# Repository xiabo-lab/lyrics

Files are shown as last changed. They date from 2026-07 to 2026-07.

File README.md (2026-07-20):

# carlyrics on Raspberry Pi 5 — Raspberry Pi OS **Lite** (64-bit)

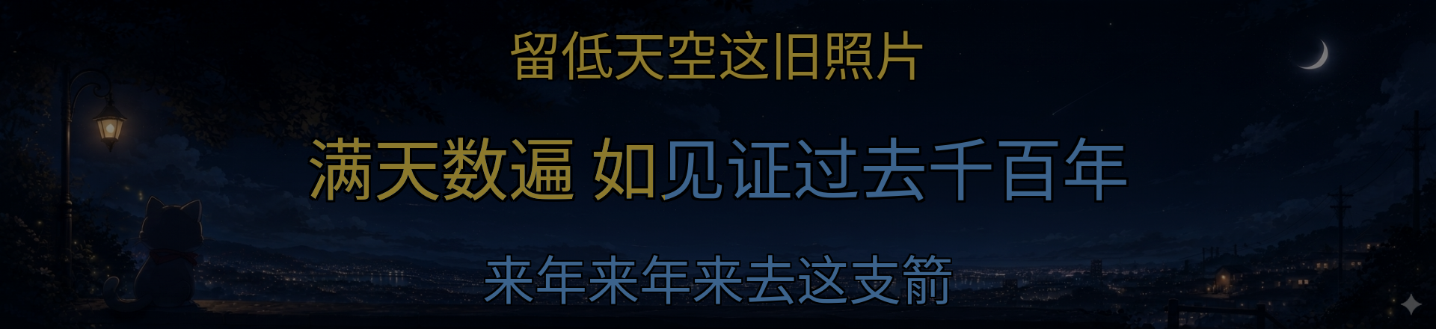
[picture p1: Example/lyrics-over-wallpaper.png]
carlyrics: time-synced, karaoke-style lyrics scrolling over a background picture on the in-car bar display


> Your phone plays music over Bluetooth; the Pi reads the playback position and
> scrolls **time-synced, karaoke-style lyrics** on a bar display in the car — no
> app on the phone, nothing to tap while driving.

Step-by-step setup for the car lyric display on a **Raspberry Pi 5** running the
**64-bit _Lite_ (console-only, no desktop)** image. Tested end-to-end on a **Pi 5
1GB**; any Pi 5 (1/2/4/8 GB) works — the app is light and never decodes audio.
**No source-code changes are required**; the code is identical to the Pi Zero 2W
build.

> 📱 **Just want to use the display once it's running?** See the
> **[First-Time Setup Guide](SETUP.md)** — a touchscreen walkthrough of every
> on-screen menu (fonts, background, Bluetooth, Wi-Fi, clock format) plus
> day-to-day use. This README covers the one-time Pi install below.

> ⚠️ **Use the _Lite_ image, not "with desktop."** The desktop image auto-starts
> its own Wayland compositor (`labwc` via `lightdm`), which grabs the HDMI output
> and fights `cage`. You'll get an endless `Swapchain … failed test` and a black
> screen. `cage` must be the **only** compositor. (Already on the desktop image?
> See *Display gotchas → #1* below to switch to console without reflashing.)

These instructions assume the Linux username **`fuwenxu`** and the install path
**`~/carlyrics`**. If your username differs, read *If your username isn't
`fuwenxu`* just below — **the one place it truly matters is the service
`ExecStart` path in Part E.**

> ### If your username isn't `fuwenxu`
>
> **The Python code needs no edits** — it resolves `config.json`, `cache/`, and
> `rejections.json` relative to the script itself, so it runs from any path. Only
> deployment paths change. Substituting `pi5` as an example:
>
> | Where | Change | Required? |
> |-------|--------|-----------|
> | systemd unit `ExecStart` (Part E) | `/home/pi5/carlyrics/Lyrics_Display.py` | **Yes — a wrong/placeholder path is the #1 reason the service fails to start** |
> | `carlyric-claude.sudoers` (Part D-3) | leading `fuwenxu` → `pi5` | Only if you use password-less restarts |
> | clone path, `ssh`/`scp` host | your username + home dir | Yes (it's just where you log in / clone) |
>
> Fix the repo files in one pass (from the repo root, after Part C):
>
> ```bash
> grep -rl fuwenxu . | xargs sed -i 's/fuwenxu/pi5/g'
> ```
>
> The systemd unit lives in `/etc/systemd/system/` (outside the repo), so set its
> path **by hand** in Part E — do not leave any `<pi-user>` placeholder in it.

---

## Hardware notes (Pi 5)

| Item | What to do |
|---|---|
| **HDMI** | Plug the bar display into **HDMI0** — the micro-HDMI port **nearest the USB-C power** connector. Needs a micro-HDMI cable/adapter. |
| **Power** | Use a **5V / 5A (25W) USB-C** supply. An under-sized car charger causes low-voltage throttling on the Pi 5 — size the car power accordingly. |
| **Cooling** | Fit the **official active cooler** or a fan case. The Pi 5 runs hot and throttles in a warm car under sustained load. |
| **RAM** | 1GB is enough (tested). More RAM gives no benefit for this app. |
| **Audio** | No 3.5mm jack, and irrelevant here — the Pi is a Bluetooth A2DP *sink* and never decodes audio (`SDL_AUDIODRIVER=dummy`). |
| **Bluetooth** | Onboard BT works the same as the Zero; pairing / `bt-agent` / AVRCP flow is unchanged. |
| **RTC (optional)** | The Pi 5 has an RTC header. A coin cell keeps the clock correct before Wi-Fi/NTP — nice for the idle-clock display. |

---

## Part A — Flash the OS

**OS: Raspberry Pi OS (64-bit) — the _Lite_ image.** 64-bit is required on the
Pi 5 (it uses the `vc4-kms-v3d` graphics stack `cage` needs).

1. Install **Raspberry Pi Imager** (<https://www.raspberrypi.com/software/>) and
   insert the microSD card.
2. In Imager:
   - **Device:** Raspberry Pi 5
   - **OS:** Raspberry Pi OS (other) → **Raspberry Pi OS Lite (64-bit)**
   - **Storage:** your microSD card
3. Click **Next → Edit Settings** and set:
   - **Hostname:** `carlyric` (so `carlyric.local` resolves on the network)
   - **Username:** `fuwenxu` + a password (keep `fuwenxu` to match the paths)
   - **Wi-Fi:** your SSID, password, and country
   - **Services tab:** enable **SSH** (password authentication)
4. **Write** the card, then insert it into the Pi 5.
5. Connect the display to **HDMI0**, apply the **5A USB-C** power, and boot.
6. After ~1 minute, SSH in from your computer:

   ```bash
   ssh fuwenxu@carlyric.local
   ```

   If `.local` doesn't resolve, use the Pi's IP from your router.

---

## Part B — Install dependencies

```bash
sudo apt update && sudo apt full-upgrade -y

sudo apt install -y python3-dbus-next python3-pygame fonts-noto-cjk \
                    cage seatd python3-requests bluez bluez-tools git uhubctl
```

`cage` is the single-app Wayland kiosk compositor; `seatd` gives it a seat
without a full desktop; `fonts-noto-cjk` provides Chinese glyphs. `uhubctl`
lets the app power-cycle the USB 5G modem's port when connectivity drops (see
**Auto-recovery** below) — optional, but recommended for in-car use.

Enable `seatd` at boot (on Lite you must do this yourself, or `cage` fails with a
`libseat`/seat error):

```bash
sudo systemctl enable --now seatd
```

---

## Part C — Get the code

Install `git` first, then clone:

```bash
sudo apt install git -y
git clone https://github.com/xiabo-lab/lyrics.git ~/carlyrics
cd ~/carlyrics
```

---

## Part D — Install the support pieces

**1. Bluetooth auto-pairing agent** (lets you pair phones from the touchscreen):

```bash
sudo cp ~/carlyrics/bt-agent.service /etc/systemd/system/
sudo systemctl enable --now bt-agent
```

**2. Stop the stray cursor** (the phone's AVRCP channel looks like a mouse):

```bash
sudo cp ~/carlyrics/99-carlyric-ignore-avrcp-pointer.rules /etc/udev/rules.d/
sudo udevadm control --reload && sudo udevadm trigger
```

**3. (Optional) password-less service restarts:**

```bash
sudo cp ~/carlyrics/carlyric-claude.sudoers /etc/sudoers.d/carlyric
sudo chmod 440 /etc/sudoers.d/carlyric
```

---

## Part E — Create the main service

The GUI needs a graphical seat (cage), so it can't run over plain SSH — it runs
from systemd. Create the unit:

```bash
sudo nano /etc/systemd/system/carlyric.service
```

Paste this exactly. **The paths below are for user `fuwenxu`. If your username
is different, replace `fuwenxu` in the `ExecStart` line — never leave a
`<pi-user>` placeholder there, or the service loops with
`can't open file '/home/<pi-user>/carlyrics/Lyrics_Display.py'`.**

```ini
[Unit]
Description=Car Lyrics Display (cage + pygame scroller)
After=systemd-user-sessions.service getty@tty1.service bluetooth.service
Wants=bluetooth.service
Conflicts=getty@tty1.service

[Service]
User=root
PAMName=login
TTYPath=/dev/tty1
StandardInput=tty
StandardOutput=journal
StandardError=journal
Environment=XDG_RUNTIME_DIR=/tmp
ExecStart=/usr/bin/cage -s -- /usr/bin/python3 -u /home/fuwenxu/carlyrics/Lyrics_Display.py
Restart=on-failure
RestartSec=3

[Install]
WantedBy=multi-user.target
```

> **Why the `tty1` binding matters (Pi 5).** At boot the kernel framebuffer
> console owns the HDMI output (DRM master). A plain background service can't take
> it, so `cage` starts but never presents — you'd see `Could not make device fd
> drm master: Device or resource busy` and endless `Swapchain … failed test`.
> `Conflicts=getty@tty1.service` + `TTYPath=/dev/tty1` + `StandardInput=tty` +
> `PAMName=login` make `cage` the **active VT session on `tty1`**, so the kernel
> hands it DRM master cleanly. Don't add any `WLR_*` env vars — not needed here.

> **`Restart=on-failure` + the `Esc` key.** With a keyboard attached, `Esc` exits
> the kiosk cleanly and it stays stopped (a real crash still auto-recovers).
> Manage the Pi over SSH — VT switching (`Ctrl+Alt+F2`) is blocked under cage on
> this board. **Do not add `OnSuccess=getty@tty1.service`**: it also fires during
> every `systemctl restart`, collides with the `tty1` hand-off, and breaks
> "Update Firmware" / manual restarts.

Save (`Ctrl+O`, `Enter`, `Ctrl+X`), then enable and start:

```bash
sudo systemctl daemon-reload
sudo systemctl enable --now carlyric.service
journalctl -t cage -f      # watch it start (see note below)
```

A healthy start logs `[config] …` and `[display] <W> x <H>`, and the lyrics
appear on the HDMI display. Press `Ctrl+C` to stop watching the log (the service
keeps running).

> **Why `python3 -u`?** systemd hands the app a journal socket, not a terminal,
> and Python block-buffers `print()` to anything that isn't a terminal. Without
> `-u`, the `[config]`/`[display]` lines above sit in a memory buffer for hours
> instead of reaching the journal — and are lost outright if the process
> crashes, which is exactly when you want them. `-u` turns buffering off so
> `[config]`, `[track]`, `[sync]` and `[lyrics]` appear live.
>
> **Why `-t cage` and not `-u carlyric.service`?** The app runs as a child of
> `cage`, so its output carries the **`cage`** syslog identifier — and because
> this unit uses `PAMName=login`, that child is placed in a `session-N.scope`
> rather than in `carlyric.service`. So `journalctl -u carlyric.service` shows
> only cage's own EGL/xwayland errors, *not* the app's lines. Filtering by
> identifier always works:
>
> ```bash
> journalctl -t cage -f | grep -E '\[(config|display|track|sync|seek|lyrics|status)\]'
> ```

**Sanity-check the path if it's looping:**

```bash
grep ExecStart /etc/systemd/system/carlyric.service   # must show YOUR real home dir
```

---

## Part F — Get the Pi online in the car (mobile hotspot)

**Only needed for in-car / outdoor use.** The Pi fetches lyrics for *new* songs
over the internet (songs you've already confirmed are cached and play offline). At
home it's on the Wi-Fi you set in Part A; in the car it needs a mobile internet
source. Set this up **once, parked**, and NetworkManager auto-connects whenever
that network is in range — nothing to do per drive.

- **Using a dedicated mobile hotspot (e.g. the TCL LINKPORT IK511 5G / T-Mobile)?**
  Add its network to the Pi once (below) and you're set — it powers up with the
  car and the Pi rejoins automatically. **Skip this part on future drives.**
- **Using your phone's hotspot?** Add the phone's hotspot the same way; the Pi
  then joins it whenever you turn Personal Hotspot on.

Add the network from your computer over SSH while the Pi is still on your home
Wi-Fi:

```bash
nano ~/carlyrics/wifi.sh    # set SSID and PASSWORD to the hotspot's
~/carlyrics/wifi.sh         # asks for the sudo password; joins and saves it
```

NetworkManager remembers every network and auto-picks whichever known one is in
range, so this is a one-time step per hotspot.

> **iPhone hotspot tip:** if the Pi won't join, toggle **Settings → Personal
> Hotspot → Maximize Compatibility** on the phone and re-run `wifi.sh`.

---

## Auto-recovery (when the internet drops)

Mobile data in the car is flaky — a 5G hotspot or USB modem can silently stop
passing traffic. The app watches for this: if **two songs in a row** get no
lyrics **and** a live reachability check confirms the internet is actually down,
it recovers automatically:

- **On a USB 5G modem** (e.g. the IK511 plugged in as a USB network adapter):
  it **power-cycles just that modem's USB port** with `uhubctl`, falling back to
  a driver re-enumeration if `uhubctl` isn't installed. Only the modem's own port
  is touched — never the touchscreen or anything else on the bus.
- **On Wi-Fi** (home Wi-Fi or a Wi-Fi hotspot): it **reboots the Pi**, which
  re-kicks NetworkManager and the radio.

Two genuinely-unfindable songs on a *working* connection never trigger it — the
reachability check gates on the internet actually being down. Turn it off with
`"auto_recover": false` in `config.json`.

---

## Part G — Pair your phone & verify

1. On the Pi screen, **long-press 10 s** → **Settings → Bluetooth → Pair New
   Phone**.
2. On your phone, pair with **`carlyric`** just like a Bluetooth speaker.
3. Play a song — lyrics should scroll in sync. Tune offsets from the on-screen
   menu or `config.json` (see [Test/README_Pi_Zero_2W.md](Test/README_Pi_Zero_2W.md)
   for every key).

**✅ That completes the required setup (Parts A–G).** If the lyrics scroll in
sync, you're done. **Everything below is optional or for troubleshooting only** —
skip it unless something isn't working or you want to migrate settings.

---

## Word-level karaoke

The current lyric line **fills with colour in time with the song** — the sung
part in `karaoke_color` (default white), the rest in `current_color`. Where the
matched lyric comes from **Kugou (KRC)** or **QQ Music (QRC)** the fill tracks
the exact word (or CJK character) being sung; otherwise it glides evenly across
the line. On by default (`karaoke_sync`) and it replaces the progress bar. QRC
decoding uses the bundled `qqcrypto.py`. Full details + the `karaoke_*` config
keys are in the [Pi Zero 2W guide](Test/README_Pi_Zero_2W.md#word-level-karaoke).

---

# Optional & troubleshooting (skip unless you need it)

## After you press `Esc` (expected behaviour, not a fault)

> **The local console looks broken — that's expected.** Two things happen once
> `cage` releases the screen:
>
> - **Undervoltage messages** may scroll by, e.g. `hwmon hwmon3: Undervoltage
>   detected!`. These were happening all along — `cage` just hid the console. They
>   mean the Pi 5 isn't getting a full 5V/5A; fix the supply/cable (a 27W USB-C PD
>   adapter + a 5A-rated cable). Check with `vcgencmd get_throttled` (`0x0` = fine,
>   `0x10000` = undervoltage occurred since boot). Don't suppress the warning.
> - **The keyboard does nothing.** The unit binds `tty1`
>   (`Conflicts=getty@tty1.service`), so with `cage` stopped there is no login
>   shell on `tty1`, and VT switching (`Ctrl+Alt+F2`) is blocked — by design you
>   manage this Pi over **SSH**. Recover with `ssh fuwenxu@carlyric.local` then
>   `sudo systemctl restart carlyric.service` (brings the display back), or
>   `sudo systemctl start getty@tty1` for a local login prompt. No other computer?
>   Power-cycle — it boots straight back into the display.

## Display gotchas (Pi 5) — only if the screen is black or wrong

Almost every "black screen / `Swapchain … failed test`" comes down to **something
other than `cage` owning the HDMI output.** In order of how often they bite:

### 1. The desktop is stealing the screen (most common)

If you flashed the **"with desktop"** image, `labwc` (started by `lightdm`) holds
DRM master and fights `cage`. Symptom: nonstop `Swapchain for output 'HDMI-A-1'
failed test`, black screen. Switch to console — no reflash needed:

```bash
systemctl get-default                 # if 'graphical.target', the desktop is on
sudo systemctl set-default multi-user.target
sudo systemctl enable --now seatd     # the desktop used to start this for you
sudo reboot
```

Confirm nothing else holds the GPU:

```bash
sudo fuser -v /dev/dri/card*          # should list only cage (+seatd), no labwc/Xorg
```

### 2. The console holds DRM master at boot

Even with no desktop, the framebuffer console owns `tty1` at boot: `Could not make
device fd drm master: Device or resource busy`. The **Part E unit fixes this** via
the `tty1` binding. If you wrote the unit without those lines, a manual run works
but boot doesn't — add them.

### 3. pygame / SDL picks the wrong video backend

The app logs `[display] <W> x <H> (SDL video driver: …)`.

- **Correct:** `[display] 1920 x 440 (SDL video driver: x11)` — SDL runs through
  cage's Xwayland. **Leave SDL on its default; do _not_ set
  `SDL_VIDEODRIVER=wayland`** (on this trixie/SDL build the native Wayland driver
  reports *"did not add any displays"* or hangs in `set_mode()`).
- **`[display] 1 x 1`** — you're hitting gotcha #1 (a second compositor is up).
  Fix the desktop conflict, not SDL.

### Harmless log lines (ignore these)

A healthy boot still prints these — they are **not** the problem:

- `[EGL] … eglQueryDeviceStringEXT … EGL_BAD_PARAMETER` — a query V3D doesn't
  support. This is the warning you'll see on every boot; safe to ignore.
- `xkbcomp … Unsupported maximum keycode 708, clipping` — keymap warning.
- `xwayland/xwm.c … Failed to get window property` / `xcb error …
  ConfigureWindow` — cosmetic Xwayland startup noise.

### Things that do *not* help (don't waste time)

- **`WLR_DRM_NO_ATOMIC` / `WLR_DRM_NO_MODIFIERS` / `WLR_NO_HARDWARE_CURSORS`** —
  only *silence* the swapchain error; the output still never reaches the app.
- **`WLR_RENDERER=vulkan`** — fails with `Could not match drm and vulkan device`.
- **`WLR_RENDERER=pixman` / `SDL_VIDEODRIVER=kmsdrm`** — both fail to start here.
- **Forcing an HDMI mode in `cmdline.txt`** — the bar panel's native mode is
  **1920×440**; forcing another mode gives a black screen. Let KMS pick the EDID
  mode; remove any `video=…` you added.

---

## (Optional) Carry over tuning from another Pi

To bring existing tuning and confirmed lyrics instead of starting blank, run from
your computer with the other Pi powered on:

```bash
# pull from the old Pi
scp    fuwenxu@<old-ip>:~/carlyrics/config.json     ./
scp -r fuwenxu@<old-ip>:~/carlyrics/cache           ./
scp    fuwenxu@<old-ip>:~/carlyrics/rejections.json ./   # if it exists
scp    fuwenxu@<old-ip>:~/carlyrics/aliases.json    ./   # saved name corrections, if any

# push to the Pi 5
scp    ./config.json     fuwenxu@carlyric.local:~/carlyrics/
scp -r ./cache           fuwenxu@carlyric.local:~/carlyrics/
scp    ./rejections.json fuwenxu@carlyric.local:~/carlyrics/
scp    ./aliases.json    fuwenxu@carlyric.local:~/carlyrics/
```

Then restart the service on the Pi 5:

```bash
sudo systemctl restart carlyric.service
```

> **Two Pis on one network:** if both are powered at once they'll both want the
> hostname `carlyric`. mDNS disambiguates (e.g. `carlyric-2.local`), but it's
> cleaner to keep only one powered during setup.

---

## Updating later

From the screen: long-press → **Software Version → Update Firmware**, or manually:

```bash
cd ~/carlyrics && git pull && sudo systemctl restart carlyric.service
```

Your `config.json`, `cache/`, `rejections.json`, and `aliases.json` (saved name
corrections) are preserved across updates.

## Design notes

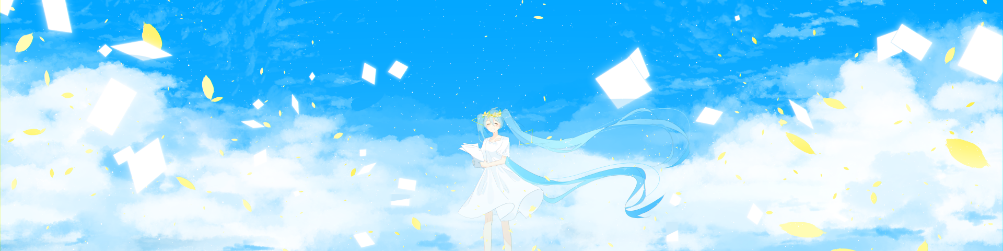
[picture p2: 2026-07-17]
Wallpaper/Sample 10.png

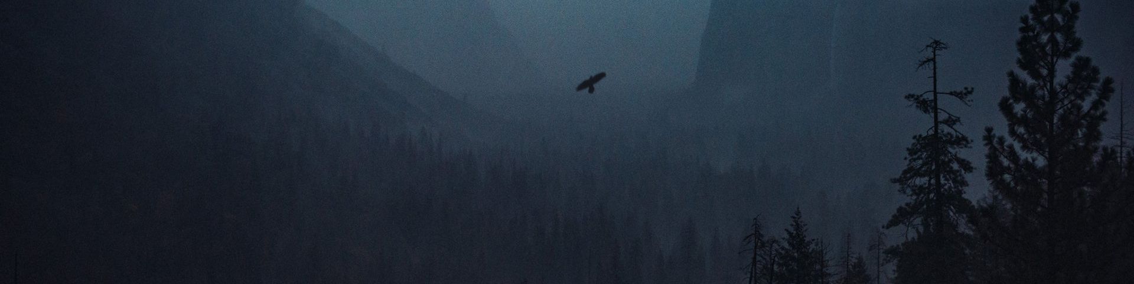
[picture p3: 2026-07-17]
Wallpaper/Sample 1.jpg

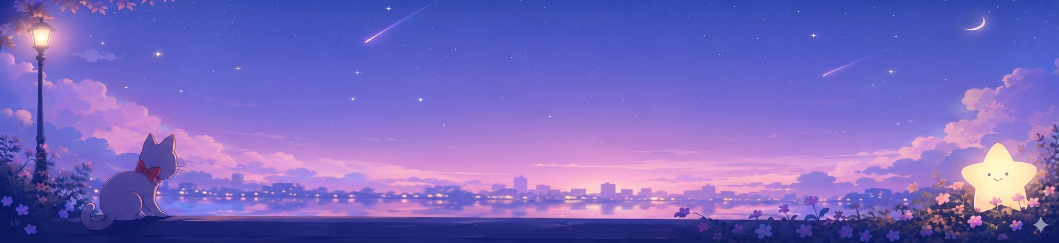
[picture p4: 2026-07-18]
Wallpaper/Sample 12.png

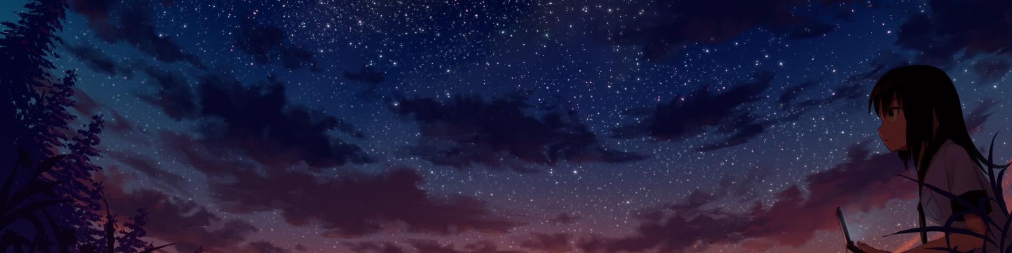
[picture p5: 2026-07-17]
Wallpaper/Sample 3.jpg

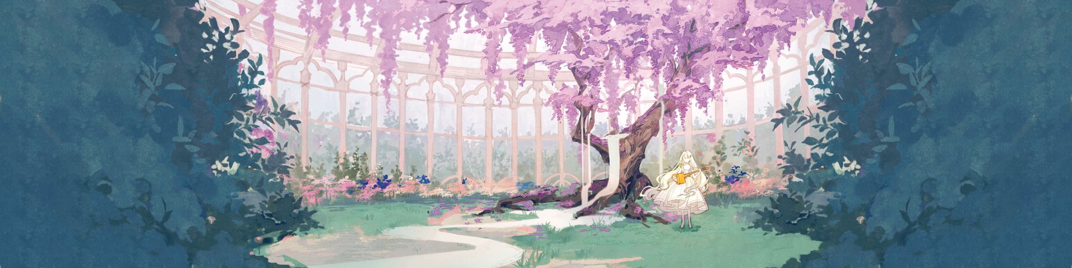
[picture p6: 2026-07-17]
Wallpaper/Sample 9.jpg

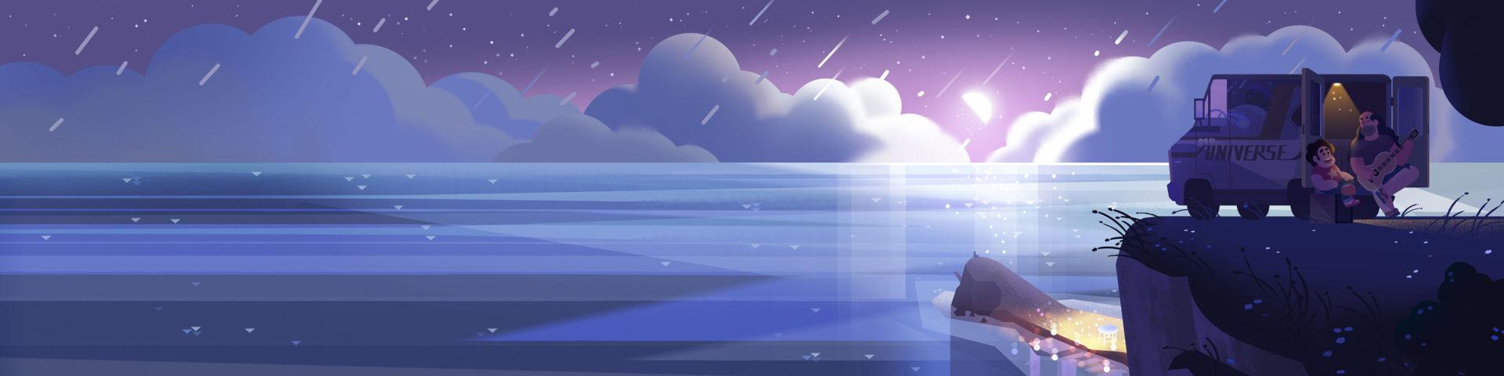
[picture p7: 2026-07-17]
Wallpaper/Sample 2.jpg

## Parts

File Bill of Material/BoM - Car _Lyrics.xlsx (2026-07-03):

 | Option 1 with Pi 5
Item | Description | Link | Price
1 | GeeekPi 11.26 inch 1920x440 HDMI LCD Capacitive Touch Screen | website (https://www.amazon.com/dp/B0F6NPCX1V?ref=ppx_yo2ov_dt_b_fed_asin_title) | $90.00
2 | Raspberry Pi 5 1 GB | website (https://www.microcenter.com/product/704295/raspberry-pi-5) | $43.00
3 | 32GB microSDHC | website (https://www.microcenter.com/product/658457/micro-center-micro-center-32gb-microsdhc-card-class-10-flash-memory-card-with-adapter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) | $10.00
4 | Phone Mount Designed for Tesla Model 3 Model Y (need 2) | Website (https://www.amazon.com/dp/B0DMVBYJG6?ref=ppx_yo2ov_dt_b_fed_asin_title) | $26.00
5 | Custom A to C (5cm) USB2 Cable if Use IK511 | Custom Make
6 | 3D Parts, Screw, Nut, Standoff | Custom Make
7 | TCL LINKPORT IK511 + Tmobile $10 montly fee for 5GB | Website (https://www.t-mobile.com/hotspot-iot-connected-devices/tcl-linkport-ik511) | $10.00
8 | Dash Cam Charger USB C, Dual Port Dashcam Power Adapter with Switch | website (https://www.amazon.com/dp/B0F93YLSRW?ref=ppx_yo2ov_dt_b_fed_asin_title&th=1) | $15.00
9 | Heatsink and Fan | Website (https://www.microcenter.com/product/688936/52pi-game5-pi-case-enlosure-shell-for-raspberry-pi-5-with-armor-lite-v5-cooler) | $14.00
 | Option 2 with Pi Zero 2W (Better Cooling and Low Power)
1 | GeeekPi 11.26 inch 1920x440 HDMI LCD Capacitive Touch Screen | website (https://www.amazon.com/dp/B0F6NPCX1V?ref=ppx_yo2ov_dt_b_fed_asin_title) | $90.00
2 | Raspberry Pi Zero 2W | Ebay | $65.00
3 | Ethernet/USB HUB HAT Expansion Board for Raspberry | Website (https://www.amazon.com/dp/B07T16RSFM?ref=ppx_yo2ov_dt_b_fed_asin_title) | $20.00
4 | Down Angle A to Down angle C USB2 cable (10CM) for IK511 | Custom Make
5 | Right up angle standard HDMI to Mini HDMI (5CM) | Custom Make
6 | 32GB microSDHC | website (https://www.microcenter.com/product/658457/micro-center-micro-center-32gb-microsdhc-card-class-10-flash-memory-card-with-adapter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) | $10.00
7 | Phone Mount Designed for Tesla Model 3 Model Y (need 2) | Website (https://www.amazon.com/dp/B0DMVBYJG6?ref=ppx_yo2ov_dt_b_fed_asin_title) | $26.00
8 | 3D Parts, Screw, Nut, Standoff | Custom Make
9 | TCL LINKPORT IK511 + Tmobile $10 montly fee for 5GB | Website (https://www.t-mobile.com/hotspot-iot-connected-devices/tcl-linkport-ik511) | $10.00
10 | Dash Cam Charger USB C, Dual Port Dashcam Power Adapter with Switch | website (https://www.amazon.com/dp/B0F93YLSRW?ref=ppx_yo2ov_dt_b_fed_asin_title&th=1) | $15.00
Notes: | $200 体验版 只包括option 1 的 ITEM #1,2,3,6

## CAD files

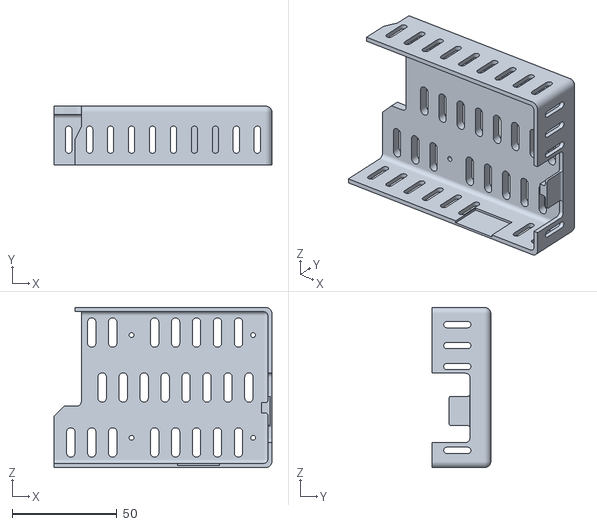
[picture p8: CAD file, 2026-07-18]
STL/Case Back #3_No_Fan.STL
104.0 x 28.0 x 76.4

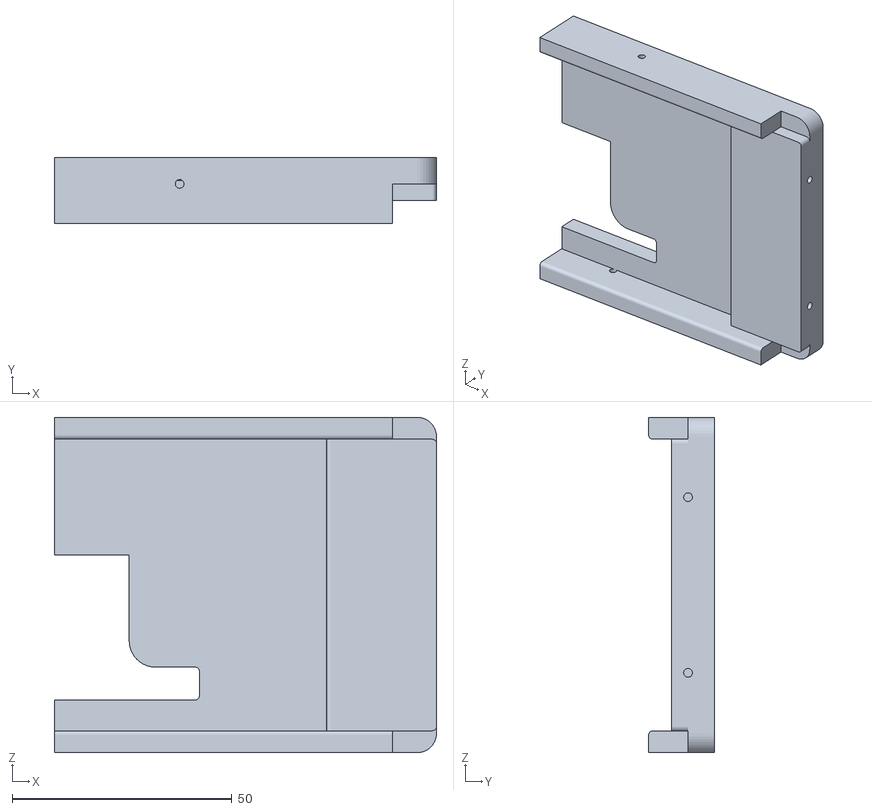
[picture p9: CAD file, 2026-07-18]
STL/Case Back #2.STL
87.0 x 15.0 x 76.4

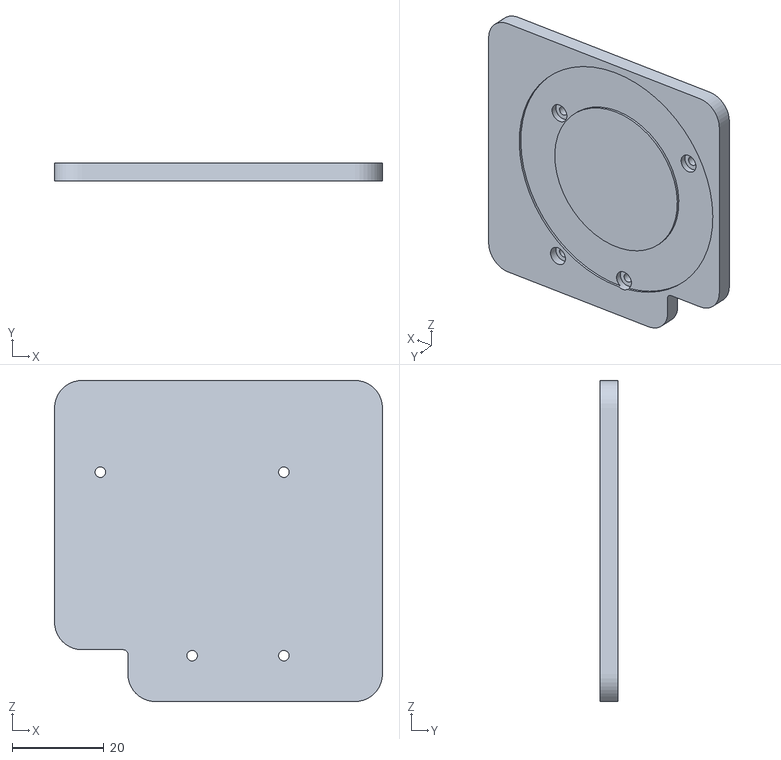
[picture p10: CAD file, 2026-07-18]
STL/Left Plate.STL
71.5 x 4.00 x 70.0

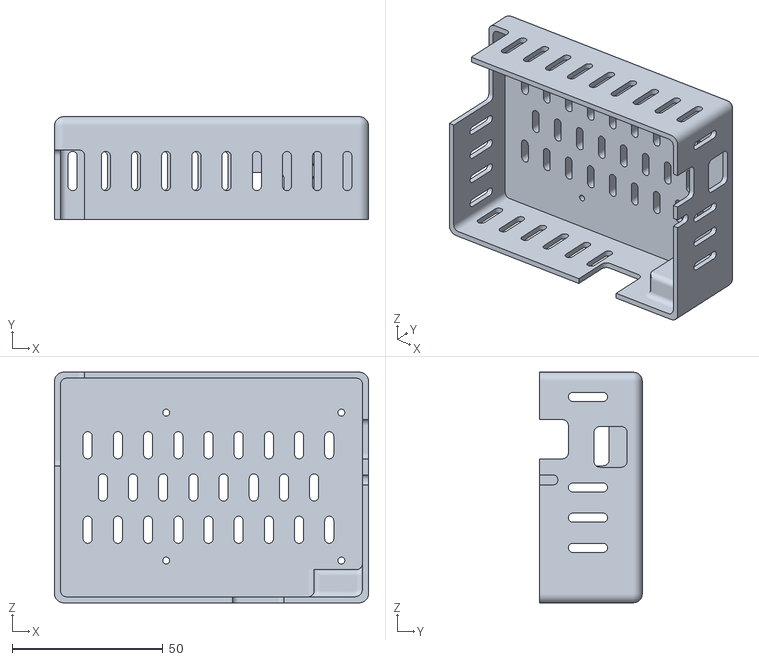
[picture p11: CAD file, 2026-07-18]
STL/Case Back #3_Zero2w.STL
104.0 x 34.0 x 76.4

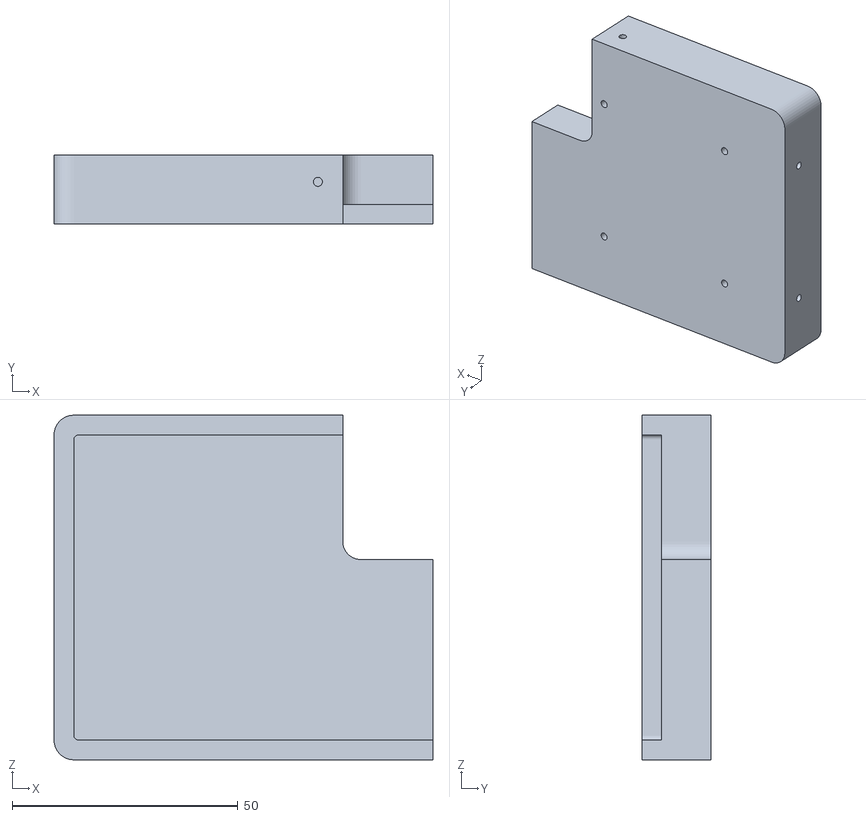
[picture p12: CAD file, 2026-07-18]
STL/Case Back #1.STL
84.0 x 15.4 x 76.4

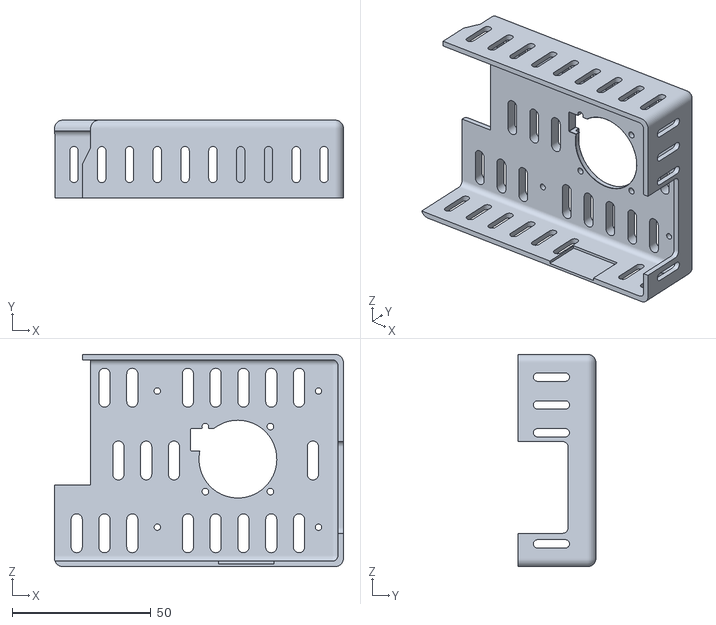
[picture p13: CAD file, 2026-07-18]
STL/Case Back #3_Fan.STL
104.0 x 28.0 x 76.4

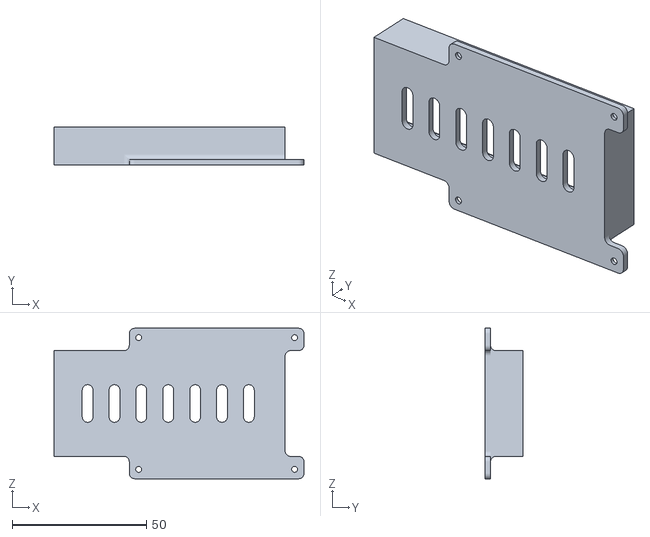
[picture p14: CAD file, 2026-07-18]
STL/Case Back #4.STL
93.0 x 14.0 x 56.0

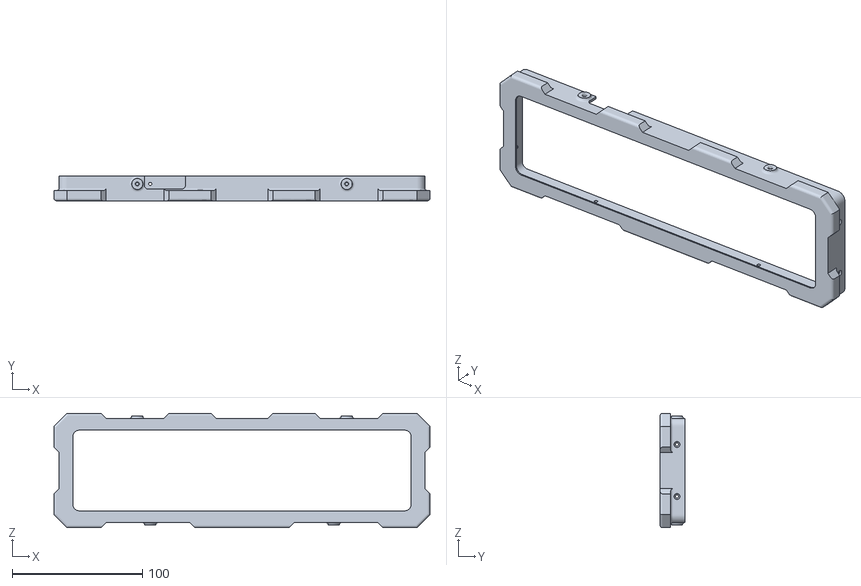
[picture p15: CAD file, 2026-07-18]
STL/Case Front.STL
289.0 x 19.0 x 88.0

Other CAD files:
STL/Right Plate.STL

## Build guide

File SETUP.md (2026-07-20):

# carlyrics — First-Time Setup Guide

Welcome! This guide walks you through setting up your **carlyrics** car lyric
display for the first time, one screen at a time. Everything is done on the
touchscreen — you never need a keyboard, mouse, or computer.

---

## Before you start

- **It turns on by itself.** When the Pi gets power, the app launches
  automatically. For the first few seconds you'll see a short **road-safety
  notice** — please only operate the settings while parked.
- **When no music is playing**, the screen shows a large **clock**.
- **When music plays** on your phone (works best with **YouTube Music**), the
  lyrics appear automatically and scroll in time with the song.

### Opening the Settings menu

> **Press and hold one finger still on the screen for about 5 seconds.**

The **Settings** menu appears with these buttons, top to bottom:

1. Font Settings
2. Background Picture
3. Bluetooth
4. Other Settings
5. Network
6. Software Version
7. **Close** (green — returns you to the lyrics/clock)

Tap any item to open it. Each screen has a **Back** button to return to this
menu.

### 🚀 Quick start — do these first

If you only do two things, do these:

1. **Bluetooth** → pair your phone (Step 3) — so the display can see your music.
2. **Network** → join your Wi‑Fi (Step 5) — so it can look up lyrics online.

Everything else below is about making it look and feel the way you like.

---

## Step 1 — Font Settings

This is where you set the **size, color, and boldness** of the on-screen text.
There are four rows, top to bottom:

| Row | What it controls |
|-----|---|
| **Karaoke fill (sung words)** | The color that "fills in" each word as it's sung. Color only — it uses the Current line's size/boldness. |
| **Top line** | The *previous* lyric line (context above the current one). |
| **Current line** | The line being sung right now — the biggest, most important line. |
| **Bottom line** | The *next* lyric line (context below). |

For each of the three "line" rows you can set:

- **Size** — drag the slider left/right (roughly 20–160 px). The label shows the
  live pixel size, e.g. *"Current line — 56px"*.
- **Color** — tap one of the 8 swatches: **Yellow, Green, White, Red, Blue,
  Purple, Black, Brown**. The selected one gets a white outline. (Black and
  Brown are there for light backgrounds.)
- **Bold / Normal** — the big button on the right toggles the weight.

**Tips**
- Changes **preview live** as you make them.
- Tap **Done** (green) to save. Settings are remembered after a restart.
- Suggested starting point: make the **Current line** large and bold, the Top
  and Bottom lines smaller.

---

## Step 2 — Background Picture

Choose what's shown *behind* the lyrics and clock. (Menus always stay on a plain
dark background so the controls remain readable.)

At the top, pick a **mode**:

### Solid Colour
Tap a color: **Black, White, Grey, Light Brown, Sky Blue.** Simple and always
readable — a good default.

### Picture
Show a photo/wallpaper behind the text. The display can switch pictures
automatically by time of day:

- **Day** row — shown from **6:00 AM to 5:59 PM**
- **Night** row — shown from **6:00 PM to 5:59 AM**

Each row shows a strip of thumbnails (use the **‹ ›** arrows to page through
more). **Tap a thumbnail in the Day row** to set your daytime picture, and **tap
one in the Night row** for nighttime. The row that's active right now is tagged
**"(now)"**, and your chosen picture in each row gets a white box around it.

> The display switches between your Day and Night pictures on its own at 6 AM and
> 6 PM — you don't have to do anything.

**Dim picture** — a **±** stepper (0–60%) that darkens the picture *only* (not the
text), so lyrics stay easy to read over a bright or busy photo.

**Adding your own pictures:** drop image files into the **`Wallpaper/`** folder on
the Pi. They look best at the screen's own resolution; other sizes are scaled to
fill and center-cropped. Your images are never overwritten by a firmware update.

Changes here **save immediately** — just tap **Back** when done.

---

## Step 3 — Bluetooth (connect your phone)

This is how the display learns which phone to read the music from.

1. Tap **Pair New Phone**. The button turns amber and the Pi becomes
   *discoverable* for a short while.
2. On **your phone**, open **Settings → Bluetooth** and tap the display's name
   in the device list. (Its name is shown on the **Software Version** screen, next
   to *"Bluetooth name"*.)
3. Accept the pairing request if your phone asks.
4. Once paired, the phone appears in the list on this screen. A
   **"• connected"** tag shows when it's actively linked.

**Notes**
- After the first pairing, the display **reconnects to your phone automatically**
  whenever it's nearby and unlocked — you normally never touch this screen again.
- If your phone is locked, iOS may refuse the connection; it links up once you
  unlock/use the phone.
- To remove a phone, tap its **Forget** button.

---

## Step 4 — Other Settings

Four adjustments for how the display behaves:

| Setting | What it does |
|---|---|
| **Rotate Screen 180°** (Yes/No) | Flip everything upside-down — use this if the screen is mounted the other way up. |
| **Bluetooth A2DP Offset** (0.0s–3.0s, steps of 0.1s) | Compensates for audio delay over Bluetooth. If lyrics run **ahead** of the sound, increase this. |
| **Lyrics Timing Offset** (−3.0s to +3.0s, steps of 0.5s) | Fine nudge for lyric timing. **Negative** = show lyrics earlier; **positive** = later. |
| **Auto Dim** (Yes/No) | Automatically dims the whole display at night so it isn't glaring while driving. |

Use the **±** buttons for the sliders and the **Yes/No** button for the toggles.
Everything saves immediately; tap **Back** when done.

> **Tip:** If lyrics feel slightly out of sync, first try **Lyrics Timing
> Offset** in small steps. Use **Bluetooth A2DP Offset** only if there's a
> consistent gap between what you *hear* and what you *see*.

---

## Step 5 — Network (join Wi-Fi)

The display needs the internet to look up lyrics. This screen shows:

- **Wi-Fi:** the network you're connected to (or *"Not connected"*)
- **IP address**
- **Internet:** **Online** (green) / **Offline** (red) / **Checking…** (amber)

To connect:

1. Tap **Wi-Fi Setup**.
2. Pick your Wi-Fi network from the list.
3. Enter the password using the **on-screen keyboard**.
4. Confirm — the display joins the network and remembers it for next time.

Tap **Check now** any time to re-test whether it's online. Tap **Back** when done.

> If you see *"Online"* in green, you're all set — lyrics will be fetched
> automatically.

---

## Step 6 — Software Version (clock format & updates)

This screen shows the app **version** and the display's **Bluetooth name**, and
has two buttons:

### Clock format
Tap the **Clock** button to switch the idle-screen clock between:

- **24-hour** — `13:05:07` (`HH:MM:SS`)
- **12-hour** — `1:05 PM` (`HH:MM AM/PM`)

It toggles each time you tap and is remembered after a restart.

### Update Firmware
Pulls the latest version of the app from the internet and restarts.

1. Tap **Update Firmware** — it arms and asks you to confirm.
2. Tap **again** to confirm. The display downloads the update and restarts on its
   own.

> Make sure you're **Online** (Step 5) before updating.

---

## Day-to-day use

- **Play music on your phone** (YouTube Music recommended) — lyrics appear and
  follow the song automatically. No music → the big **clock** is shown.
- **If the lyrics for a song look wrong or are missing**, on-screen feedback
  buttons let you fix it:
  - **Green** — confirm the current lyrics are correct (saves them for next time).
  - **Red** — open a picker to choose a different match or **search manually**
    (with an on-screen keyboard, including pinyin input for Chinese titles).
  - **Triple-tap** — remove the saved lyric for the current song so it's looked
    up fresh.
- **To change any setting later**, just hold a finger on the screen for ~5
  seconds to reopen the menu.

---

## Troubleshooting quick reference

| Problem | Try this |
|---|---|
| No lyrics, only the clock | Make sure music is **playing** and the phone is **connected** (Step 3). |
| "Offline" / no lyrics found | Rejoin **Wi-Fi** (Step 5), then tap **Check now**. |
| Lyrics slightly out of sync | Adjust **Lyrics Timing Offset** (Step 4) in small steps. |
| Screen is upside-down | Turn on **Rotate Screen 180°** (Step 4). |
| Text hard to read on a photo | Increase **Dim picture** (Step 2) or pick a **Solid Colour** background. |
| Phone won't reconnect | Unlock the phone; if needed, **Forget** and **Pair** again (Step 3). |

---

*Enjoy your carlyrics display — and please only adjust settings while parked.*

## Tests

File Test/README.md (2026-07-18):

# carlyrics

A car karaoke lyric display for the Raspberry Pi. Your phone plays music over
Bluetooth; the Pi reads the playback position and scrolls time-synced lyrics on a
screen mounted in the car — no app on the phone, nothing to tap while driving.

The current line **fills with colour in time with the song**, word-by-word where
the source provides it (Kugou KRC / QQ QRC), so it reads like real karaoke. See
**[Word-level karaoke](../README.md#word-level-karaoke)** in the setup guide.

Everything below is set on the screen itself — long-press the display for 10
seconds to open Settings. Nothing needs a keyboard or a config file.

## Look and feel

- **Font Settings** — size, weight and colour for the top / current / bottom
  lines, plus the karaoke fill colour. Eight colours, including Black and Brown
  for use over a light backdrop.
- **Background Picture** — the lyric screen's backdrop is either a solid colour
  (Black, White, Grey, Light Brown, Sky Blue) or a picture from `Wallpaper/`, with
  an optional slideshow (30 min – 4 h) and a **Dim picture** control for busy
  or bright pictures. Drop your own images into `Wallpaper/` and they appear in the
  picker without a restart — no update overwrites them.
  > Pictures are scaled to **fill** the panel and centre-cropped, so match your
  > panel's aspect ratio (the screen tells you its exact size) or the top and
  > bottom of the image are trimmed.
- Lyrics are drawn with an **outline**, so they stay readable over any picture,
  and the backdrop dims along with the text at night.

## Setup guides

The application code is identical across boards — only the OS-setup steps differ.
Pick the guide for yours:

- **Raspberry Pi 5 — Lite OS** (the primary, supported build; tested on a Pi 5
  1GB) → **[README.md](../README.md)** (the repo's main page)
- **Raspberry Pi 5 — full "with desktop" OS** (tested on a Pi 5 8GB) →
  **[README_Pi5.md](README_Pi5.md)**
- **Raspberry Pi Zero 2W** → **[README_Pi_Zero_2W.md](README_Pi_Zero_2W.md)**

> ⚠️ `cage` must be the only thing driving the screen. The **Lite** (console-only,
> 64-bit) image gives that out of the box; on a "with desktop" image you switch
> the Pi to boot to console (the Pi 5 full-OS guide covers this). Either way, if a
> desktop compositor (labwc) keeps running, the lyrics never appear.

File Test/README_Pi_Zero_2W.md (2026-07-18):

# carlyrics

A car karaoke lyric display for the Raspberry Pi. Your phone plays music over
Bluetooth; the Pi reads the *playback position* from the phone and scrolls
time-synced lyrics on a screen mounted in the car — in time with the song, with
no app to install on the phone and nothing to tap while driving.

It's built for a Chinese-leaning music library (the lyric search leads with
Chinese catalogues) but works with anything that has synced lyrics online.

> ⚠️ Personal hobby project. It talks to several **unofficial** music-lyric
> endpoints that can change or disappear at any time. No affiliation with, or
> endorsement by, Apple, Google, Tencent (QQ Music), Kugou, NetEase, or LRCLIB.

---

## ⚠️ Road safety

**This is a glance-only display. Your attention belongs on the road, not the
screen.** Treat it like a passenger singing along — never stare at it, and never
operate its touch controls (menus, Bluetooth pairing, the lyric picker) while
the car is moving. Do all setup and tuning **parked, or on a home desktop.** The
app shows a brief safety reminder at every startup for this reason.

Driving safely is your responsibility. The author accepts no liability for use
of this hobby project; use it only in a way that is legal where you drive and
that keeps your eyes on the road.

---

## How it works

```
  Phone (Apple Music / YouTube Music / …)
        │  Bluetooth A2DP audio  ──────────────►  car stereo
        │  AVRCP metadata + position
        ▼
  Raspberry Pi (this project)
        │  BlueZ D-Bus: org.bluez.MediaPlayer1   → "what song, where in it?"
        │  lyric cascade (cache → online sources) → time-stamped .lrc
        ▼
  HDMI bar display (cage + pygame kiosk)        → the scrolling lyrics
```

- **Position, not audio.** The Pi acts as a Bluetooth speaker (A2DP sink +
  AVRCP controller). It never needs to decode the audio — it asks BlueZ for the
  current track and playback position and extrapolates a local clock between
  updates. Apple Music broadcasts position ~once a second (tight sync); YouTube
  Music only on play/pause/skip (sync is re-anchored at those events).
- **Lyric cascade.** For each track it tries a local cache first, then a series
  of online lyric providers, stopping at the first that returns *synced* lyrics
  (lines with `[mm:ss.xx]` timestamps). Plain unsynced lyrics are rejected.
- **Latency & lead tuning.** Two offsets shift the lyrics relative to the audio
  so a line is already on screen when you reach it — see `config.json`.

---

## Hardware

> **Tested platform.** This project is tested and run **only on a Raspberry Pi
> Zero 2W with Raspberry Pi OS _Lite_ (64-bit, no desktop).** Other Pi models and
> images may work but are not validated. Use a **Lite / console-only** image: a
> "with desktop" image runs its own Wayland compositor (labwc, via the display
> manager) that holds the screen and fights `cage` for it, so the lyrics never
> appear. If you must use a desktop image, switch the Pi to boot to console
> (`sudo systemctl set-default multi-user.target`). For the Raspberry Pi 5,
> follow the separate [README_Pi5.md](README_Pi5.md), which covers its extra
> boot/seat quirks.

- Raspberry Pi (developed on a Pi 4 / Pi OS Bookworm, 64-bit; **tested in-car on
  a Pi Zero 2W with Pi OS Lite**).
- A display — designed for a wide "bar" LCD (e.g. 1920×440), mounted above the
  dash. Works on any HDMI screen; set `flip_180` if it's mounted upside-down.
- A touchscreen is optional but recommended — all on-screen controls
  (settings menu, feedback buttons, brightness) are touch gestures.
- Built-in Bluetooth (or a USB BT dongle).

---

## Repository layout

| File | Purpose |
|---|---|
| `README.md` | The Raspberry Pi 5 Lite setup guide (the repo's main page). |
| `Lyrics_Display.py` | The app: BlueZ/AVRCP watcher, sync clock, pygame renderer, on-screen settings + Bluetooth pairing menu. |
| `lyric_sources.py` | Multi-source synced-lyric fetcher (QQ / Kugou / NetEase / LRCLIB): one concurrent sweep, best-match scored, with on-disk cache and the RED-button picker grid. Prefers word-by-word lyrics (Kugou KRC / QQ QRC) where available. |
| `lrclib.py` | LRCLIB client + the `.lrc` parser (`parse_lrc`, handles enhanced/word-level LRC) and `LyricLine`/`Word` types. |
| `qqcrypto.py` | Pure-Python decryptor for QQ's word-by-word QRC lyrics (QQ's "buggy DES"). |
| `config.json` | Live, hot-reloaded tuning (offsets, fonts, colours, brightness, …). |
| `Font/Aldrich-Regular.ttc` / `Font/advanced_led_board-7.ttc` | Idle-clock fonts (square Aldrich in use; LED alt bundled). Missing → the clock falls back to Noto. |
| `Assets/*icon.png` / `Assets/*icon.jpg` | Per-source badges (QQ / Kugou / NetEase / LRCLIB) shown on picker results. |
| `pinyin_table.json` | Offline pinyin→Hanzi table for the Modify Search IME. |
| `build_pinyin_table.py` | One-off generator that (re)builds `pinyin_table.json`. |
| `bt-agent.service` | systemd unit for the headless Bluetooth pairing agent. |
| `99-carlyric-ignore-avrcp-pointer.rules` | udev rule so the phone's AVRCP device isn't treated as a mouse (stops a stray cursor). |
| `wifi.sh` | One-shot helper to join a new Wi-Fi network via NetworkManager. |
| `carlyric-claude.sudoers` | Optional sudoers snippet allowing password-less service restart. |
| `test_lyrics.py` | Unit tests for the pure logic (lrc parsing, lock policy, line indexing). |
| `Assets/` | Picker source-badge icons. |
| `Font/` | Idle-clock fonts (shipped via the OTA sync list). |
| `Wallpaper/` | Background pictures for Settings → Background Picture; drop your own here (bundled `Sample 1–13`, live-scanned at runtime). |
| `Example/` | Sample photos of the display, for the docs. |
| `Bill of Material/` | Parts list for building the display (BoM spreadsheet). |
| `Test/` | Archived setup guides (Pi 5 full-desktop, Pi Zero 2W, the overview README) plus scratch/manual test scripts from development (display, touch, AVRCP probes). |
| `cache/` | Confirmed lyrics, one `.lrc` per song (created at runtime; git-ignored). |
| `rejections.json` | Songs you've triple-tap-deleted, so they aren't re-cached (created at runtime; git-ignored). |
| `LICENSE` | MIT licence. |

---

## Part A — Flash the OS

**OS: Raspberry Pi OS (64-bit) — use the _Lite_ image (no desktop).** This is the
tested platform: **Pi Zero 2W + Pi OS Lite**. A "with desktop" image runs its own
Wayland compositor (`labwc`, via the display manager) that holds the screen and
fights `cage`, so the lyrics never appear. If you must use a desktop image, switch
the Pi to boot to console (`sudo systemctl set-default multi-user.target`).

1. Install **Raspberry Pi Imager** (<https://www.raspberrypi.com/software/>) and
   insert the microSD card.
2. In Imager:
   - **Device:** Raspberry Pi Zero 2W
   - **OS:** Raspberry Pi OS (other) → **Raspberry Pi OS Lite (64-bit)**
   - **Storage:** your microSD card
3. Click **Next → Edit Settings** (the OS customization dialog) and set:
   - **Hostname:** `carlyric` (so `carlyric.local` resolves on the network)
   - **Username:** `fuwenxu` + a password (keep `fuwenxu` to match the project's
     paths, or see *Changing the username* below)
   - **Wi-Fi:** your SSID, password, and country
   - **Services tab:** enable **SSH** (password authentication)
4. **Write** the card, insert it into the Pi, connect the HDMI display, and power
   on.
5. After ~1 minute, SSH in from your computer:

   ```bash
   ssh fuwenxu@carlyric.local
   ```

   If `.local` doesn't resolve, use the Pi's IP from your router instead.

---

## Part B — Install dependencies

```bash
sudo apt update
sudo apt install -y python3-dbus-next python3-pygame fonts-noto-cjk \
                    cage seatd python3-requests bluez bluez-tools uhubctl
```

`cage` is a single-app Wayland kiosk compositor; `seatd` gives it a seat without
a full desktop. `fonts-noto-cjk` is required for Chinese glyphs. `uhubctl` lets
the app power-cycle the USB 5G modem's port on a connectivity drop (see
**Auto-recovery** below) — optional, but recommended for in-car use.

Enable `seatd` so it starts at boot (on a Lite/console image you must enable it
yourself, or `cage` fails with a `libseat`/seat error):

```bash
sudo systemctl enable --now seatd
```

---

## Part C — Get the code

Install `git` first, then clone:

```bash
sudo apt install git -y
git clone https://github.com/xiabo-lab/lyrics.git ~/carlyrics
```

> **Pick your username.** The helper files and the example service unit assume
> the Linux user `fuwenxu` and the path `/home/fuwenxu/carlyrics`. If your Pi
> user is different, change it — see
> [Changing the username](#changing-the-username) below.

---

## Part D — Install the support pieces

**1. Bluetooth auto-pairing agent** (lets you pair phones from the touchscreen —
the Pi has no keyboard to confirm a pairing, so `bt-agent` (NoInputNoOutput)
auto-accepts the "Just Works" pairing modern phones use):

```bash
sudo cp ~/carlyrics/bt-agent.service /etc/systemd/system/
sudo systemctl enable --now bt-agent
```

**2. Stop the stray cursor** (the phone's AVRCP control channel looks like a
mouse to the compositor, which pops a cursor on screen — this udev rule ignores
it):

```bash
sudo cp ~/carlyrics/99-carlyric-ignore-avrcp-pointer.rules /etc/udev/rules.d/
sudo udevadm control --reload && sudo udevadm trigger
```

**3. (Optional) password-less service restarts** (if you redeploy often, lets a
non-root user restart the service without a password prompt — edit the username
first):

```bash
sudo cp ~/carlyrics/carlyric-claude.sudoers /etc/sudoers.d/carlyric
sudo chmod 440 /etc/sudoers.d/carlyric
```

---

## Part E — Create the main service

The GUI needs a graphical seat (cage), so it can't be launched over a plain SSH
session — run it from systemd. Create the unit:

```bash
sudo nano /etc/systemd/system/carlyric.service
```

Paste this exactly. **The paths below are for user `fuwenxu`. If your username is
different, replace `fuwenxu` in the `ExecStart` line with your real username —
never leave a `<pi-user>` placeholder there, or the service loops with
`can't open file '/home/<pi-user>/carlyrics/Lyrics_Display.py': [Errno 2] No such
file or directory`.**

```ini
[Unit]
Description=Car Lyrics Display (cage + pygame scroller)
After=bluetooth.service seatd.service
Wants=bluetooth.service

[Service]
User=root
Environment=XDG_RUNTIME_DIR=/tmp
ExecStart=/usr/bin/cage -s -- /usr/bin/python3 -u /home/fuwenxu/carlyrics/Lyrics_Display.py
Restart=always
RestartSec=3

[Install]
WantedBy=multi-user.target
```

Sanity-check the path if it's looping:

```bash
grep ExecStart /etc/systemd/system/carlyric.service   # must show YOUR real home dir
```

Then enable and start:

```bash
sudo systemctl daemon-reload
sudo systemctl enable --now carlyric.service
journalctl -t cage -f      # watch it start (see note below)
```

A healthy start logs `[config] …`, `[display] <W> x <H>`, and on a track change
`[track] <artist> — <title>` followed by a lyric source hit.

> **Why `python3 -u`?** systemd hands the app a journal socket, not a terminal,
> and Python block-buffers `print()` to anything that isn't a terminal. Without
> `-u`, the `[config]`/`[display]` lines above sit in a memory buffer for hours
> instead of reaching the journal — and are lost outright if the process
> crashes, which is exactly when you want them. `-u` turns buffering off so
> `[config]`, `[track]`, `[sync]` and `[lyrics]` appear live.
>
> The app runs as a child of `cage`, so its output carries the **`cage`** syslog
> identifier rather than `python3`. Filtering by identifier keeps the app's own
> lines and drops cage's EGL/xwayland noise:
>
> ```bash
> journalctl -t cage -f | grep -E '\[(config|display|track|sync|seek|lyrics|status)\]'
> ```

---

## Part F — Get the Pi online in the car (mobile hotspot)

**Only needed for in-car / outdoor use.** The Pi fetches lyrics for *new* songs
over the internet (songs you've already confirmed are cached and play offline). At
home it's on the Wi-Fi you set in Part A; in the car it needs a mobile internet
source. Set this up **once, parked**, and NetworkManager auto-connects whenever
that network is in range — nothing to do per drive.

- **Using a dedicated mobile hotspot (e.g. the TCL LINKPORT IK511 5G / T-Mobile)?**
  Add its network to the Pi once (below) and you're set — it powers up with the
  car and the Pi rejoins automatically. **Skip this part on future drives.**
- **Using your phone's hotspot?** Add the phone's hotspot the same way; the Pi
  then joins it whenever you turn Personal Hotspot on.

Add the network from your computer over SSH while the Pi is still on your home
Wi-Fi:

```bash
nano ~/carlyrics/wifi.sh    # set SSID and PASSWORD to the hotspot's
~/carlyrics/wifi.sh         # asks for the sudo password; joins and saves it
```

NetworkManager remembers every network and auto-picks whichever known one is in
range, so this is a one-time step per hotspot (this is the same `wifi.sh` covered
under *Wi-Fi* below).

> **The Pi Zero 2W is 2.4 GHz-only.** The hotspot must broadcast a **2.4 GHz**
> band or the Zero won't see it. On iPhone, turn on **Settings → Personal Hotspot
> → Maximize Compatibility** (forces 2.4 GHz); the TCL IK511 and most Android
> hotspots already expose a 2.4 GHz SSID.

---

## Auto-recovery (when the internet drops)

Mobile data in the car is flaky — a 5G hotspot or USB modem can silently stop
passing traffic. The app watches for this: if **two songs in a row** get no
lyrics **and** a live reachability check confirms the internet is actually down,
it recovers automatically:

- **On a USB 5G modem** (e.g. the IK511 plugged in as a USB network adapter):
  it **power-cycles just that modem's USB port** with `uhubctl`, falling back to
  a driver re-enumeration if `uhubctl` isn't installed. Only the modem's own port
  is touched — never the touchscreen or anything else on the bus.
- **On Wi-Fi** (home Wi-Fi or a Wi-Fi hotspot): it **reboots the Pi**, which
  re-kicks NetworkManager and the radio.

Two genuinely-unfindable songs on a *working* connection never trigger it — the
reachability check gates on the internet actually being down. Turn it off with
`"auto_recover": false` in `config.json`.

---

## Part G — Pair your phone & verify

1. On the Pi screen, **long-press 10 s** → **Settings → Bluetooth → Pair New
   Phone**.
2. On your phone, pair with **`carlyric`** just like a Bluetooth speaker. This is
   a one-time step — afterwards the app auto-connects on boot, and you can swap in
   a *replacement* phone from this same menu (the Pi keeps one phone paired at a
   time).
3. Play a song — lyrics should scroll in sync. Tune offsets from the on-screen
   menu or `config.json` (see *Configuration* below for every key).

**✅ That completes the required setup (Parts A–G)** — the lyrics display now
starts on boot and reconnects your phone. Everything below is optional or
reference; skip it unless you need it.

---

# Reference & optional (skip unless you need it)

Everything below is background, tuning reference, and troubleshooting — the
display already works after Parts A–G above. Read a section only when you need it.

## Changing the username

The repo was developed with the Linux user **`fuwenxu`**, which appears as a
hard-coded example in a few places. To use your own Pi user, replace `fuwenxu`
with your username (e.g. the Raspberry Pi OS default `pi`) in these files:

| File | What to change |
|---|---|
| `carlyric-claude.sudoers` | the leading `fuwenxu` (the user granted password-less restart). |
| `wifi.sh` | the `ssh fuwenxu@…` hint printed on success. |
| The systemd unit (Step 5 above) | `User=` and the `/home/fuwenxu/carlyrics` path in `ExecStart`. |
| `Lyrics_Display.py` (top docstring) | the example `scp`/run commands — comments only, cosmetic. |
| `Test/*.py` (docstrings) | example paths/commands — comments only, cosmetic. |

A quick way to do them all at once (run from the repo root on the Pi, swapping
`YOURNAME`):

```bash
grep -rl fuwenxu . | xargs sed -i 's/fuwenxu/YOURNAME/g'
```

The home-directory path must also match wherever you cloned the repo
(`/home/YOURNAME/carlyrics`). Nothing here depends on the literal name
`fuwenxu` — it's purely the account the files were written for.

---

## Configuration (`config.json`)

`config.json` lives next to the script and **hot-reloads within ~1 second** —
edit it while the app runs and the change takes effect with no restart. A
missing or malformed key silently falls back to a safe default, so a bad edit
can never blank the screen. Code changes still need a service restart.

| Key | Meaning |
|-----|---|
| `lead_offset_ms` | How far *ahead* of the audio to show each line (positive = lyrics lead). |
| `latency_offset_ms` | Compensation for Bluetooth A2DP audio buffering. |
| `font_current` / `font_top` / `font_bottom` | Font px for the now line / previous line / next line. |
| `current_color` / `top_color` / `bottom_color` | Named palette colour per line (yellow, green, white, red, blue, purple). |
| `current_bold` / `top_bold` / `bottom_bold` | Render each line (now / previous / next) bold. |
| `show_prev_line` | Show the previous lyric above the current one. |
| `karaoke_sync` | Karaoke fill: the current line's colour sweeps left→right in time (per-word when the source has word timing — see **Word-level karaoke** — else across the whole line). Replaces the progress bar when on. Default `true`. |
| `karaoke_color` | The *sung* colour of the karaoke fill (palette name); the not-yet-sung part uses `current_color`. Default `white`. |
| `progress_bar` | Thin progress bar under the current line. Ignored while `karaoke_sync` is on (the fill already shows progress). |
| `intro_dots_max` | Pre-song countdown dots (1 dot ≈ 1 second). |
| `line_gap_pad` | Extra spacing between stacked lines. |
| `target_fps` | Render frame rate. |
| `dim_enabled` / `day_start_hour` / `night_start_hour` / `night_brightness` | Automatic night dimming. |
| `max_line_width_frac` | Shrink-to-fit any line wider than this fraction of the screen. |
| `flip_180` | Rotate the whole frame 180° for an upside-down mount. |
| `autoconnect` | Auto-reconnect AVRCP to the paired phone on boot / after a drop. |
| `auto_recover` | Auto-recover lost internet after two lyric-less songs (see **Auto-recovery**). Default `true`. |

Most font/colour values are also editable live from the on-screen menu (below),
which writes them back to `config.json`.

---

## Word-level karaoke

The current lyric line **fills with colour left→right in time with the song** —
the already-sung part in `karaoke_color` (default white), the rest in
`current_color`. This replaces the old progress bar (`karaoke_sync`, default on).

How precisely the fill tracks the words depends on what the source provides:

- **Per-word / per-character timing** when the matched lyric comes from **Kugou
  (KRC)** or **QQ Music (QRC)** — the fill edge lands on the exact word (or CJK
  character) being sung. QRC needs `qqcrypto.py` (bundled).
- **Line-level fill** otherwise (NetEase, LRCLIB, or any plain `.lrc`) — the edge
  glides evenly across the line over its duration. Still a smooth karaoke sweep,
  just not word-accurate.

Both are automatic — no configuration beyond the two `karaoke_*` keys. Songs
cached before this feature stay line-level until re-fetched (delete a cached
lyric with a triple-tap, or clear `cache/`, to pull the word-level version).

---
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

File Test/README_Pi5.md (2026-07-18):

# carlyrics on Raspberry Pi 5

Step-by-step setup for running the car lyric display on a **Raspberry Pi 5**,
**tested on an 8GB board running the full Raspberry Pi OS (64-bit, "with
desktop")** switched to console boot. The application code is identical to the Pi
Zero 2W build — **no source changes are required.** The only differences are the
OS image you flash and a few physical details (HDMI port, power, cooling).

> **Running the Lite (console-only) image instead?** Follow the leaner
> [the Lite guide](../README.md) — same result with fewer steps (there's
> no desktop to switch off). This guide covers the full "with desktop" image.

These instructions assume the Linux user `fuwenxu` and the install path
`~/carlyrics`, matching the rest of the project. If you use a different
username, see *Changing the username* in [README_Pi_Zero_2W.md](README_Pi_Zero_2W.md) and adjust
the paths below.

> ### If your username isn't `fuwenxu`
>
> **The Python code needs no edits** — it resolves `config.json`, `cache/`, and
> `rejections.json` relative to the script itself
> (`Path(__file__).resolve().parent`), so it runs from any path. The `fuwenxu`
> strings inside the `.py` files are comments/example commands only.
>
> Only deployment details change. Substituting `pi5` as an example:
>
> | Where | Change | Required? |
> |-------|--------|-----------|
> | systemd unit `ExecStart` (Part E) | `/home/pi5/carlyrics/Lyrics_Display.py` | **Yes** — wrong path = service won't start |
> | `carlyric-claude.sudoers` (Part D-3) | leading `fuwenxu` → `pi5` | Only if you use password-less restarts |
> | clone path / `ssh` & `scp` host below | use your username + home dir | Yes (it's just where you log in / clone) |
> | `wifi.sh` hint, `.py` docstrings | cosmetic | No |
>
> Fix the repo files in one pass (run from the repo root on the Pi, after Part C):
>
> ```bash
> grep -rl fuwenxu . | xargs sed -i 's/fuwenxu/pi5/g'
> ```
>
> The systemd unit lives in `/etc/systemd/system/` (outside the repo), so set its
> path by hand in Part E.

---

## Hardware notes (Pi 5 vs. Pi Zero 2W)

| Item | What to do on the Pi 5 |
|---|---|
| **HDMI** | Plug the bar display into **HDMI0** — the micro-HDMI port **nearest the USB-C power** connector. Needs a micro-HDMI cable/adapter. |
| **Power** | Use a **5V / 5A (25W) USB-C** supply. A car charger that ran the Zero will likely under-power the Pi 5 and cause low-voltage throttling — size the car power accordingly. |
| **Cooling** | Fit the **official active cooler or a case with a fan**. The Pi 5 runs hot and will throttle in a warm car under sustained load. |
| **Audio** | No 3.5mm jack on the Pi 5 — irrelevant here. The Pi is a Bluetooth A2DP *sink* feeding the car stereo and never decodes audio (`SDL_AUDIODRIVER=dummy`). No change needed. |
| **Bluetooth** | Onboard BT works the same as the Zero; the pairing / `bt-agent` / AVRCP flow is unchanged. |
| **RTC (optional)** | The Pi 5 has a real-time-clock header. A coin cell keeps the clock correct before Wi-Fi/NTP — nice for the idle-clock display. |

---

## Part A — Flash the OS

**OS: Raspberry Pi OS (64-bit).** This guide is tested with the **full "with
desktop"** image on a Pi 5 (8GB). 64-bit is required on the Pi 5 (it uses the
`vc4-kms-v3d` graphics stack that `cage` needs).

> ⚠️ **The desktop must not run at the same time as `cage`.** The desktop's
> `labwc` Wayland compositor (auto-started by `lightdm`) grabs the HDMI output and
> holds DRM master, so `cage` can never own the screen — you'd get an endless
> `Swapchain for output 'HDMI-A-1' failed test` and a black display. `cage` must
> be the *only* compositor, so **Step 7 below switches the Pi to boot to
> console.** (Prefer to avoid this entirely? Use the Lite image and
> [the Lite guide](../README.md).)

1. Install **Raspberry Pi Imager** (<https://www.raspberrypi.com/software/>) on
   your computer and insert the microSD card.
2. In Imager:
   - **Device:** Raspberry Pi 5
   - **OS:** Raspberry Pi OS (64-bit)  *(the standard "with desktop" image)*
   - **Storage:** your microSD card
3. Click **Next → Edit Settings** (the OS customization dialog) and set:
   - **Hostname:** `carlyric` (so `carlyric.local` resolves on the network)
   - **Username:** `fuwenxu` + a password (keep `fuwenxu` to match the
     project's paths)
   - **Wi-Fi:** your SSID, password, and country
   - **Services tab:** enable **SSH** (password authentication)
4. **Write** the card. When finished, insert it into the Pi 5.
5. Connect the display to **HDMI0**, apply the **5A USB-C** power, and boot.
6. After ~1 minute, SSH in from your computer:

   ```bash
   ssh fuwenxu@carlyric.local
   ```

   If `.local` doesn't resolve, use the Pi's IP from your router instead.
7. **Switch to console boot** so the desktop compositor never fights `cage`:

   ```bash
   sudo systemctl set-default multi-user.target
   sudo reboot
   ```

   After the reboot the Pi comes up to a console (no desktop). SSH back in and
   continue with Part B.

---

## Part B — Install dependencies

```bash
sudo apt update && sudo apt full-upgrade -y

sudo apt install -y python3-dbus-next python3-pygame fonts-noto-cjk \
                    cage seatd python3-requests bluez bluez-tools git uhubctl
```

`cage` is the single-app Wayland kiosk compositor; `seatd` gives it a seat
without a full desktop; `fonts-noto-cjk` provides Chinese glyphs. `uhubctl`
lets the app power-cycle the USB 5G modem's port when connectivity drops (see
**Auto-recovery** below) — optional, but recommended for in-car use.

Enable `seatd` so it starts at boot (on the desktop image the login manager
pulled it in for you; on Lite/console you must enable it yourself, or `cage`
fails with a `libseat`/seat error):

```bash
sudo systemctl enable --now seatd
```

---

## Part C — Get the code

Install `git` first, then clone:

```bash
sudo apt install git -y
git clone https://github.com/xiabo-lab/lyrics.git ~/carlyrics
cd ~/carlyrics
```

---

## Part D — Install the support pieces

**1. Bluetooth auto-pairing agent** (lets you pair phones from the touchscreen):

```bash
sudo cp ~/carlyrics/bt-agent.service /etc/systemd/system/
sudo systemctl enable --now bt-agent
```

**2. Stop the stray cursor** (the phone's AVRCP channel looks like a mouse):

```bash
sudo cp ~/carlyrics/99-carlyric-ignore-avrcp-pointer.rules /etc/udev/rules.d/
sudo udevadm control --reload && sudo udevadm trigger
```

**3. (Optional) password-less service restarts:**

```bash
sudo cp ~/carlyrics/carlyric-claude.sudoers /etc/sudoers.d/carlyric
sudo chmod 440 /etc/sudoers.d/carlyric
```

---

## Part E — Create the main service

The GUI needs a graphical seat (cage), so it can't run over plain SSH — it runs
from systemd. Create the unit:

```bash
sudo nano /etc/systemd/system/carlyric.service
```

Paste exactly (paths already set for user `fuwenxu`):

```ini
[Unit]
Description=Car Lyrics Display (cage + pygame scroller)
After=systemd-user-sessions.service getty@tty1.service bluetooth.service
Wants=bluetooth.service
Conflicts=getty@tty1.service

[Service]
User=root
PAMName=login
TTYPath=/dev/tty1
StandardInput=tty
StandardOutput=journal
StandardError=journal
Environment=XDG_RUNTIME_DIR=/tmp
ExecStart=/usr/bin/cage -s -- /usr/bin/python3 -u /home/fuwenxu/carlyrics/Lyrics_Display.py
Restart=on-failure
RestartSec=3

[Install]
WantedBy=multi-user.target
```

> **Why the `tty1` binding matters (Pi 5).** At boot the kernel framebuffer
> console owns the HDMI output (DRM master). A plain background service can't
> take it, so `cage` starts but can never present — you'd see
> `Could not make device fd drm master: Device or resource busy` and endless
> `Swapchain … failed test`. `Conflicts=getty@tty1.service` + `TTYPath=/dev/tty1`
> + `StandardInput=tty` + `PAMName=login` make `cage` the **active VT session on
> `tty1`**, so the kernel hands it DRM master cleanly. Don't add any `WLR_*` env
> vars — they're not needed and were a red herring on this hardware.

> **`Restart=on-failure` + the `Esc` key.** With a keyboard attached, `Esc`
> exits the kiosk cleanly; `Restart=on-failure` then leaves it stopped (a real
> crash still auto-recovers). Manage the Pi over SSH from there — VT switching
> (`Ctrl+Alt+F2`) is blocked under cage on this board. **Do not add
> `OnSuccess=getty@tty1.service`** to get a login prompt after `Esc`: it also
> fires during every `systemctl restart`, which collides with the `tty1`
> hand-off and **breaks "Update Firmware"** and manual restarts.

Save (`Ctrl+O`, `Enter`, `Ctrl+X`), then enable and start:

```bash
sudo systemctl daemon-reload
sudo systemctl enable --now carlyric.service
journalctl -t cage -f      # watch it start (see note below)
```

A healthy start logs `[config] …` and `[display] <W> x <H>`, and the lyrics
screen appears on the HDMI display. Press `Ctrl+C` to stop watching the log (the
service keeps running).

> **Why `python3 -u`?** systemd hands the app a journal socket, not a terminal,
> and Python block-buffers `print()` to anything that isn't a terminal. Without
> `-u`, the `[config]`/`[display]` lines above sit in a memory buffer for hours
> instead of reaching the journal — and are lost outright if the process
> crashes, which is exactly when you want them. `-u` turns buffering off so
> `[config]`, `[track]`, `[sync]` and `[lyrics]` appear live.
>
> **Why `-t cage` and not `-u carlyric.service`?** The app runs as a child of
> `cage`, so its output carries the **`cage`** syslog identifier — and because
> this unit uses `PAMName=login`, that child is placed in a `session-N.scope`
> rather than in `carlyric.service`. So `journalctl -u carlyric.service` shows
> only cage's own EGL/xwayland errors, *not* the app's lines. Filtering by
> identifier always works:
>
> ```bash
> journalctl -t cage -f | grep -E '\[(config|display|track|sync|seek|lyrics|status)\]'
> ```

---

## Part F — Get the Pi online in the car (mobile hotspot)

**Only needed for in-car / outdoor use.** The Pi fetches lyrics for *new* songs
over the internet (songs you've already confirmed are cached and play offline). At
home it's on the Wi-Fi you set in Part A; in the car it needs a mobile internet
source. Set this up **once, parked**, and NetworkManager auto-connects whenever
that network is in range — nothing to do per drive.

- **Using a dedicated mobile hotspot (e.g. the TCL LINKPORT IK511 5G / T-Mobile)?**
  Add its network to the Pi once (below) and you're set — it powers up with the
  car and the Pi rejoins automatically. **Skip this part on future drives.**
- **Using your phone's hotspot?** Add the phone's hotspot the same way; the Pi
  then joins it whenever you turn Personal Hotspot on.

Add the network from your computer over SSH while the Pi is still on your home
Wi-Fi:

```bash
nano ~/carlyrics/wifi.sh    # set SSID and PASSWORD to the hotspot's
~/carlyrics/wifi.sh         # asks for the sudo password; joins and saves it
```

NetworkManager remembers every network and auto-picks whichever known one is in
range, so this is a one-time step per hotspot.

> **iPhone hotspot tip:** if the Pi won't join, toggle **Settings → Personal
> Hotspot → Maximize Compatibility** on the phone and re-run `wifi.sh`.

---

## Auto-recovery (when the internet drops)

Mobile data in the car is flaky — a 5G hotspot or USB modem can silently stop
passing traffic. The app watches for this: if **two songs in a row** get no
lyrics **and** a live reachability check confirms the internet is actually down,
it recovers automatically:

- **On a USB 5G modem** (e.g. the IK511 plugged in as a USB network adapter):
  it **power-cycles just that modem's USB port** with `uhubctl`, falling back to
  a driver re-enumeration if `uhubctl` isn't installed. Only the modem's own port
  is touched — never the touchscreen or anything else on the bus.
- **On Wi-Fi** (home Wi-Fi or a Wi-Fi hotspot): it **reboots the Pi**, which
  re-kicks NetworkManager and the radio.

Two genuinely-unfindable songs on a *working* connection never trigger it — the
reachability check gates on the internet actually being down. Turn it off with
`"auto_recover": false` in `config.json`.

---

## Part G — Pair your phone & verify

1. On the Pi screen, **long-press 10 s** → **Settings → Bluetooth → Pair New
   Phone**.
2. On your phone, pair with **`carlyric`** just like a Bluetooth speaker.
3. Play a song — lyrics should scroll in sync. Tune offsets from the on-screen
   menu or `config.json` (see [README_Pi_Zero_2W.md](README_Pi_Zero_2W.md) for every key).

**✅ That completes the required setup (Parts A–G).** If the lyrics scroll in
sync, you're done. **Everything below is optional or for troubleshooting only** —
skip it unless something isn't working or you want to migrate settings.

---

## Word-level karaoke

The current lyric line **fills with colour in time with the song** — the sung
part in `karaoke_color` (default white), the rest in `current_color`. Where the
matched lyric comes from **Kugou (KRC)** or **QQ Music (QRC)** the fill tracks
the exact word (or CJK character) being sung; otherwise it glides evenly across
the line. On by default (`karaoke_sync`) and it replaces the progress bar. QRC
decoding uses the bundled `qqcrypto.py`. Full details + the `karaoke_*` config
keys are in the [Pi Zero 2W guide](README_Pi_Zero_2W.md#word-level-karaoke).

---

# Optional & troubleshooting (skip unless you need it)

## After you press `Esc` (expected behaviour, not a fault)

> **The local console looks broken — that's expected.** Two things happen once
> `cage` releases the screen:
>
> - **Undervoltage messages** may scroll by, e.g. `hwmon hwmon3: Undervoltage
>   detected!`. These were happening all along — `cage` just hid the console. They
>   mean the Pi 5 isn't getting a full 5V/5A; fix the supply/cable (a 27W USB-C PD
>   adapter + a 5A-rated cable). Check with `vcgencmd get_throttled` (`0x0` = fine,
>   `0x10000` = undervoltage occurred since boot). Don't suppress the warning.
> - **The keyboard does nothing.** The unit binds `tty1`
>   (`Conflicts=getty@tty1.service`), so with `cage` stopped there is no login
>   shell on `tty1`, and VT switching (`Ctrl+Alt+F2`) is blocked — by design you
>   manage this Pi over **SSH**. Recover with `ssh fuwenxu@carlyric.local` then
>   `sudo systemctl restart carlyric.service` (brings the display back), or
>   `sudo systemctl start getty@tty1` for a local login prompt. No other computer?
>   Power-cycle — it boots straight back into the display.

## Pi 5 display gotchas (only if the screen is black or wrong)

Almost every "black screen / `Swapchain … failed test`" problem on the Pi 5 comes
down to **something other than `cage` owning the HDMI output**. `cage` must be the
only thing driving the display. In order of how often they bite:

### 1. The desktop is stealing the screen (most common)

If you flashed the **"with desktop"** image, `labwc` (the desktop's Wayland
compositor, started by `lightdm`) holds DRM master and fights `cage`. Symptom:
nonstop `Swapchain for output 'HDMI-A-1' failed test`, black screen.

Check and fix — boot to console instead of the desktop:

```bash
systemctl get-default                 # if 'graphical.target', the desktop is on
sudo systemctl set-default multi-user.target
sudo systemctl enable --now seatd     # desktop used to start this for you
sudo reboot
```

To confirm nothing else holds the GPU:

```bash
sudo fuser -v /dev/dri/card*          # should list only cage (+seatd), no labwc/Xorg
```

### 2. The console holds DRM master at boot

Even with no desktop, the kernel framebuffer console owns `tty1` at boot, so a
plain service can't get the display: `Could not make device fd drm master:
Device or resource busy`. The **Part E unit fixes this** by binding `cage` to
`tty1` (`Conflicts=getty@tty1.service`, `TTYPath`, `StandardInput=tty`,
`PAMName=login`). If you wrote the unit without those lines, the manual run works
but boot doesn't — add them.

### 3. pygame / SDL picks the wrong video backend

The app opens its window with `pygame.display.set_mode((0,0), FULLSCREEN)` and
logs the result: `[display] <W> x <H> (SDL video driver: …)`.

- **Correct:** `[display] 1920 x 440 (SDL video driver: x11)` — SDL runs through
  cage's Xwayland. **Leave SDL on its default; do _not_ set
  `SDL_VIDEODRIVER=wayland`.** On this trixie/SDL 2.32 build the native Wayland
  driver either reports *"The video driver did not add any displays"* or hangs
  forever inside `set_mode()` (black screen, only a cursor).
- **`[display] 1 x 1`** — you're hitting gotcha #1 (a second compositor is up),
  which corrupts Xwayland's screen size. Fix the desktop conflict, not SDL.

### Harmless log lines (ignore these)

A healthy boot still prints these — they are **not** the problem:

- `[EGL] … eglQueryDeviceStringEXT … EGL_BAD_PARAMETER` — a query V3D doesn't support.
- `xkbcomp … Unsupported maximum keycode 708, clipping` — keymap warning.
- `xwayland/xwm.c … Failed to get window property` / `xcb error … ConfigureWindow` — cosmetic Xwayland startup noise.

### Things that do *not* help (don't waste time)

- **`WLR_DRM_NO_ATOMIC` / `WLR_DRM_NO_MODIFIERS` / `WLR_NO_HARDWARE_CURSORS`** —
  these only *silence* the swapchain error; the output still never reaches the
  app. The real cause is always "who owns the display," above.
- **`WLR_RENDERER=vulkan`** — fails with `Could not match drm and vulkan device`
  (the Pi splits display=vc4 and render=v3d into separate DRM devices).
- **`WLR_RENDERER=pixman` / `SDL_VIDEODRIVER=kmsdrm`** — both fail to start here.
- **Forcing an HDMI mode in `cmdline.txt`** (e.g. `video=HDMI-A-1:1920x1080@60`)
  — the bar panel's native mode is **1920×440**; forcing a mode it can't show
  gives a black screen. Let KMS pick the EDID mode; remove any `video=…` you added.

---

## (Optional) Carry over tuning from the Pi Zero

To bring your existing tuning and confirmed lyrics instead of starting blank,
run these from your computer with the Zero powered on:

```bash
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

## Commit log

2026-06-25 Add multi-source lyric picker + triple-tap delete; v1.5.0
    - RED button now opens a consolidated 3x3 picker of candidate lyrics from
    all sources (QQ<=3, Kugou<=3, NetEase<=1, LRCLIB<=2, 9 total). Selecting a
    cell shows that version and keeps BOTH feedback buttons up until GREEN
    confirms/caches; RED reopens the grid.
    - Triple-tap a displayed lyric to delete it from the cache ("This lyric has
    been deleted.").
    - Add lyric_sources.search_candidates() multi-result gatherer and
    lrclib.search_synced_lyrics() (LRCLIB /search endpoint).
    - Fix: holding a finger on the picker grid no longer trips the long-press
    into Settings or wedges its buttons (drain FINGERUP, clear stale fingers,
    suppr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
2026-06-25 Enlarge picker text + drop source chip; v1.5.1
    The 3x3 lyric picker was hard to read from the driver's seat. Remove the
    source chip (QQ/Kugou/NetEase/LRCLIB) from each cell and use the freed space
    for a large, centred song title with the artist below it, sized off the cell
    height. The source is still tracked internally for caching. Bump APP_VERSION
    1.5.0 -> 1.5.1.
2026-06-25 Add Other Settings submenu; v1.5.3
    New long-press → Settings → Other Settings screen with four controls:
    - Rotate Screen 180° (flip_180) — Yes/No toggle
    - Bluetooth A2DP Offset (latency_offset_ms) — ± stepper, 0–3 s / 0.1 s
    - Lyrics Timing Offset (lead_offset_ms) — ± stepper, -3…+3 s / 0.5 s
    - Auto Dim (dim_enabled) — Yes/No toggle
    Each tap previews live and persists to config.json immediately, riding
    the same hot-reload path as the font panel. Bumps APP_VERSION so OTA applies.
2026-06-25 Show idle clock instead of waiting-for-music note; v1.5.4
    When no track is playing, the idle screen now shows a clock:
    - top line: current time HH:MM:SS (24-hour)
    - middle line: today's date MM/DD/YYYY
    - bottom line: "Waiting for Music"
    Also clear state.title/artist on a track stop so the idle clock branch is
    actually reached after a song ends (previously stale meta kept the title
    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
2026-06-28 Add Pi 5 setup guide (README_Pi5.md)
    Standalone step-by-step setup for running carlyrics on a Raspberry Pi 5
    (8GB) with a fresh microSD card: OS flash, dependencies, code, services,
    pairing, and optional tuning migration from the Pi Zero. App code is
    unchanged from the Zero build; only OS image and hardware (HDMI0, 5A
    USB-C, active cooling) differ.
2026-06-28 Release v1.5.6: Esc exits kiosk; Pi 5 service Restart=on-failure + OnSuccess
    Lyrics_Display.py: only Esc (or a window QUIT) exits the render loop; all other
    keys are ignored, so a stray keypress on an attached keyboard can no longer drop
    the kiosk into a restart loop. APP_VERSION 1.5.5 -> 1.5.6.
    README_Pi5.md: Pi 5 systemd unit now uses Restart=on-failure plus
    OnSuccess=getty@tty1.service, so a deliberate Esc exit stays exited and returns a
    login prompt on the screen.
2026-06-28 Release v1.5.7: drop OnSuccess=getty@tty1 (it broke updates/restarts)
    OnSuccess=getty@tty1.service fired during every `systemctl restart` (including
    the one "Update Firmware" runs), handing tty1 to getty mid-restart and colliding
    with cage's tty1 binding — leaving the kiosk dead after an update.
    - README_Pi5.md: remove OnSuccess from the Pi 5 unit; add a note explaining why
    it must not be re-added, and that Esc exits cleanly with Restart=on-failure.
    - Lyrics_Display.py: fix the stale Esc comment; APP_VERSION 1.5.6 -> 1.5.7.
2026-06-28 Rename README.md -> README_Pi_Zero_2W.md (Pi Zero 2W / OS Lite is the tested target)
    The main guide is specific to the only tested platform — a Pi Zero 2W on
    Raspberry Pi OS Lite — so name it accordingly and drop the generic README.md.
    Added a "Tested platform" callout (use a Lite/console image; a desktop image's
    labwc fights cage). README_Pi5.md cross-links updated to the new filename.
2026-06-28 Add a tiny index README.md linking the two platform guides
    Restores the GitHub landing page after the rename: points to
    README_Pi_Zero_2W.md (tested platform) and README_Pi5.md, and reminds to use a
    Lite/console image.
2026-06-29 Bake per-song sync nudge into cached lyrics on green confirm (v1.5.8)
    When the user has nudged a song's sync with the two-finger swipe and then
    taps the green button, shift the saved LRC timestamps by -song_offset_ms so
    the adjustment is baked into the cache and survives restarts — no need to
    re-nudge the same song next time. The in-memory lines are rewritten and the
    live nudge zeroed so the current display is unchanged.
    - lrclib: add shift_lrc_timestamps(lrc, delta_ms)
    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
2026-06-29 Docs: explain saving a per-song sync fix (swipe first, then Green)
    Document that the two-finger sync nudge can be made permanent by confirming
    with Green, which bakes the adjustment into the cached lyrics so the song
    plays in sync on every future play. Emphasize the required order — swipe to
    fix first, THEN press Green — and how to recover if Green was pressed early.
2026-07-03 Docs: note the dead local console + undervoltage lines after Esc (Pi 5)
    Pressing Esc exits the kiosk but leaves tty1 without a login shell (the
    unit conflicts getty@tty1), so the local keyboard does nothing and VT
    switching is blocked — manage over SSH. Also explain the undervoltage
    messages that appear once cage releases the console. Added to both the
    Pi 5 and Pi 5 Lite guides.
2026-07-03 Docs: separate required steps (A-F) from optional/troubleshooting (Pi 5)
    Part F (pair the phone) is a required step but sat *after* the display
    troubleshooting, making the whole tail look like debugging. Reorder so
    Parts A-F are contiguous, add a "setup complete" marker, then group the
    Esc note, display gotchas, tuning migration and update notes under a
    clear "Optional & troubleshooting (skip unless you need it)" banner.
2026-07-03 Docs: mark end of required setup + group reference/optional (Pi Zero 2W)
    Add a "required setup complete (steps 1-5)" marker after the service
    starts, and a top-level "Reference & optional (skip unless you need it)"
    banner before the username/config/controls/updating/wifi/tests sections,
    so it's clear which steps are required vs reference material.
2026-07-03 Docs: Pi 5 guide = full desktop OS (8GB); Pi Zero setup in Part A-F format
    - README_Pi5.md: state it's tested on the full "with desktop" 64-bit OS
    on a Pi 5 (8GB); Part A now flashes the desktop image and adds a step
    to switch to console boot so cage owns the screen; point Lite users to
    README_Pi5_Lite.md.
    - README_Pi_Zero_2W.md: restructure "Setup on the Pi" into the same
    Part A-F layout as the Pi 5 guides. Add Part A (flash the OS) and a
    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
2026-07-07 v1.5.9: fix AVRCP stuck-at-boot and slow bt-agent shutdown
    Autoconnect: when a phone is linked at the Bluetooth level but no
    MediaPlayer1 has surfaced (iOS cold-boot brings up A2DP audio without
    opening the AVCTP control channel), force ConnectProfile(AVRCP) on that
    connected phone instead of doing nothing. Previously the display hung at
    "waiting for music" until a manual power cycle. Still one source at a
    time — only already-connected phones are targeted in that case.
    bt-agent.service: send SIGKILL as the first stop signal (KillSignal)
    instead of SIGTERM, which bt-agent ignores. Removes the multi-second
    wait on every shutdown; the agent holds no state needing cleanup.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
2026-07-07 v1.6.0: add Settings → Network screen (online status)
    New read-only Network screen in the settings menu so the user can check
    whether the Pi is online without SSH. Shows the Wi-Fi SSID, LAN IP, and a
    colour-coded Internet status (Online/Offline/Checking) from an active TCP
    connect to github.com:443 — the reachability that OTA updates and lyric
    fetching actually depend on. Auto-checks on open, with a Check-now button
    to re-probe. All blocking work (iwgetid/nmcli, hostname, socket) runs off
    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
2026-07-07 v1.7.0: Modify Search editor + pinyin IME; balanced/faster picker
    RED picker: 8 results balanced 2-per-source, backfilled to 8, and the four
    sources are now queried concurrently (~3x faster). The lower-right cell is a
    "Modify Search" button opening an on-screen editor to correct a garbled
    artist/song and re-search.
    Modify Search editor (Lyrics_Display.py): QWERTY with caret editing (◀ ▶),
    search-by-song-name-only (artist optional), Back/Search, and a 中/A toggle for
    a full offline pinyin→Hanzi IME — composition buffer, paged candidate strip
    (« » through all candidates), tap to insert. Table is Simplified, generated by
    build_pinyin_table.py and shipped as pinyin_table.json (both i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
2026-07-07 Rename BoM - Car _Lyrics.xlsx to Bill of Material/BoM - Car _Lyrics.xlsx
    [BoM - Car _Lyrics.xlsx]
2026-07-08 Score all search results across sources; cache them for the RED picker
    The lyric cascade took the first search result each source returned, which is
    often the wrong version of a song (a Live cut, a cover, a different artist).
    Search engines rank by popularity, not by whether it's the track the phone is
    actually playing.
    Now one concurrent sweep queries all four sources, scores every candidate
    against the requested title + artist, and displays the highest scorer:
    score = 0.65*title_sim + 0.35*artist_sim
    - 0.35 if the LRC has <5 timestamps (credits-only stub)
    + <=0.003 source bias (breaks exact ties only, old cascade order)
    Titles/artists are NFKC-folded and stripped o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
2026-07-14 v1.9.0: auto-recovery, idle clock redesign, QQ fix, picker source/duration
    Connectivity auto-recovery (ConnectivityRecovery): after two consecutive
    lyric-less songs AND a failed reachability probe, power-cycle the USB 5G
    modem's port via uhubctl (unbind/rebind fallback) or reboot on Wi-Fi. New
    config key auto_recover (default true). Adds uhubctl dependency.
    Idle clock screen: just a big HH:MM:SS clock filling 3/4 of the screen, in a
    bundled font (fnt/Aldrich-Regular.ttc; LED alt fnt/advanced_led_board-7.ttc),
    hour red / minute yellow / second green, on a fixed monospaced grid so digits
    don't drift, ink-centered for equal spacing. Date and "Waiting for Music"
    removed. get_font/draw_line take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
2026-07-15 Karaoke fill on the current line (replaces the progress bar)
    Current line colour sweeps left→right in time with the line: sung portion in
    karaoke_color (default white), unsung in the current-line colour. Timing is
    interpolated from the line's own duration (plain LRC has no per-word times).
    New config: karaoke_sync (default true; suppresses the progress bar when on),
    karaoke_color. New draw_karaoke_line() composites two renders and blits the
    sung colour over the left frac*width px.
2026-07-15 Word-level karaoke: Kugou KRC + enhanced-LRC parsing/rendering
    Foundation for true word-by-word karaoke (vs the earlier line-level fill):
    lrclib.py: new Word type; LyricLine gains a `words` list; parse_lrc reads
    enhanced-LRC inline word tags <mm:ss.xx> (absolute times), returning [] for
    plain lines and skipping words on repeated-timestamp lines. shift_lrc_timestamps
    now shifts word tags too so a baked nudge stays aligned.
    lyric_sources.py: Kugou KRC support — base64→krc1 magic→XOR(16-byte key)→zlib
    decrypt, then convert `[start,dur]<off,dur,0>word…` to enhanced LRC with
    absolute per-word times. _kugou_lyric prefers KRC, falls back to plain LRC.
    Lyrics_Display.py: draw_karaoke_li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
2026-07-15 Word-level karaoke: QQ QRC (buggy-DES) support
    Adds the third word-level format. qqcrypto.py is a clean pure-Python port of
    QQ Music's "buggy DES" (a few S-box entries differ from FIPS-46 DES — the whole
    reason a stock DES lib can't decrypt QRC), in a 3DES-EDE arrangement with the
    fixed 24-byte QRC key. Ported from the MIT-licensed C# reference
    WXRIW/QQMusicDecoder (this project is MIT; LDDC's Python port is GPL, so not
    used). Runs on the Pi's ARM Linux (the usual reference needs a Windows DLL);
    ~0.5s per song.
    lyric_sources.py: QRC download via lyric_download.fcg (needs the numeric
    musicid, so _qq_search_list now returns (musicid, songmid) keys); decrypt →
    _qrc_to_enhanced_lrc (QRC wor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
2026-07-15 README: document word-level karaoke
    Add a "Word-level karaoke" section and the karaoke_sync/karaoke_color config
    keys (Pi Zero guide), note qqcrypto.py in the file manifest, and a headline
    mention on the landing page. Explains per-word timing via Kugou KRC / QQ QRC
    vs the line-level fill fallback.
2026-07-15 v1.9.1: ship idle-clock fonts + picker source icons via OTA
    Close the OTA asset gap. The fonts and source-badge icons weren't in
    UPDATE_FILES, so OTA-updated devices fell back to the Noto clock font and
    showed no source icons.
    - Move the clock fonts out of fnt/ to the repo root so every UPDATE_FILES entry
    is top-level — a subdir entry would abort OTA on older installs that lack the
    dir (their apply loop can't create it). CLOCK_FONT_PATH updated accordingly.
    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
2026-07-15 v1.9.2: fix karaoke fill misalignment on lines with edge whitespace
    parse_lrc stripped LyricLine.text but not the per-word `words`, so
    text != "".join(words) whenever a line had leading/trailing whitespace (real
    QRC lines commonly end with a space). draw_karaoke_line renders `text` while
    _karaoke_split_px measures word widths against the word concatenation, so the
    mismatch offset the sung/unsung edge — by a full space-width for any line with
    LEADING whitespace.
    Fix: trim outer whitespace off the edge words and derive `text` from the word
    concatenation, so the two are always identical. Verified on real QQ QRC (2
    mismatched lines → 0) and added a regression test. 43/43 pass.
    Co-Authored-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
2026-07-17 v1.9.3: don't anchor lyrics to the phone's stale track-start positions
    Lyrics ran ~1.4s behind the music for a whole song after each track
    change, until a manual pause/play snapped them right.
    Measured on the rig (iPhone/YouTube Music, BlueZ 5.82): at track start
    the phone's Position reports queue behind its track-metadata burst and
    arrive ~1s stale, each staler than the last -- 198ms@2.56s, 305ms@3.25s,
    647ms@3.60s. All imply the audio began at ~2.4-3.0s, but pausing (which
    forces a truthful report) proves it began at 1.53s. YouTube Music then
    broadcasts nothing for the rest of the song, so that bad anchor is never
    corrected; pause/play is the only thing that replaces it.
    Once locked, _ha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
2026-07-17 Docs: run the app unbuffered, and give a journalctl command that works
    Two fixes to the setup guides, both found while trying to read the app's
    logs on the real Pi.
    1. `python3 -u` in ExecStart. systemd hands the app a journal socket, not a
    terminal, and Python block-buffers print() to anything that isn't one. The
    guides already promised "a healthy start logs [config] ... and [display]
    <W> x <H>" -- but those lines sat in a memory buffer instead of reaching
    the journal, and would be lost entirely on a crash. -u makes the
    documented behaviour actually true.
    2. `journalctl -u carlyric.service -f` never showed the app's output. The app
    runs as a child of cage, so its lines c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
2026-07-17 Backgrounds: new sample pictures, and a half-hour slideshow stepper
    Replace the three stock backdrops with eight samples. The originals were
    1855x848 (2.19:1) against a 4.36:1 panel, so cover-crop threw away ~half their
    height and their bright skies washed out the lyric text -- light text on a light
    photo does not read. The samples are 1920x480, so they lose only ~20px to the
    crop and are dark enough to sit behind text. Repo drops from 5.6MB to 2.1MB.
    Slideshow interval now steps in whole half-hours (30 min .. 4 h, one tap = 30
    min) instead of 15s steps from a 5s floor: reaching a useful interval took ~35
    taps, which is how the live config ended up at an arbitrary 530s. Shown as
    "30 min" /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
2026-07-17 Palettes: Brown for lyric text; Light Brown and Sky Blue backdrops
    Brown joins the lyric colours (all four rows). Light Brown and Sky Blue join
    the solid backdrops, which had only Black / White / Grey.
    The background screen had the same hardcoded-count bug the font panel just
    had: `_btn_row(..., 3)` fixed the solid row at three buttons, so the two new
    colours would have been laid out on top of each other. It now follows
    len(BG_SOLID_COLORS).
    Two more things the new names broke:
    - str.capitalize() renders "light brown" as "Light brown". Labels now come from
    the palette itself (BG_COLOR_LABELS), so the display name is authoritative.
    - The button label colour was hardcoded ("black if white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
2026-07-17 Make lyrics read over a picture: outline the text, dim the backdrop
    The lyrics went washed-out once a picture was behind them. Measured on the rig
    at night (Sample 3, night_brightness 0.55), text-vs-picture contrast was
    3.98 / 4.42 / 3.31 : 1 for top/current/bottom — all under the 4.5:1 readable
    bar, against 12.7 / 14.4 / 10.8 in daylight.
    Root cause was a bug in the background feature: scale_color dims the TEXT for
    night auto-dim (and the manual brightness slider), but paint_lyric_background
    never dimmed the PICTURE. Pale grey glyphs on a photo still at full blast. On a
    black backdrop that was harmless, which is why it only showed up now — and it
    also defeated the point of dimming at n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
2026-07-18 docs: make Pi 5 Lite guide the main README; archive other-board guides to Test/
    Promote README_Pi5_Lite.md to README.md so GitHub's main page shows the
    supported Pi 5 Lite (64-bit) build. Move the overview README (now covering all
    three boards) and the Pi 5 full-desktop / Pi Zero 2W guides into Test/. Fix all
    internal cross-links to resolve under the new layout.
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2026-07-18 feat: rename image/ background folder to Wallpaper/; add Sample 11-13
    Rename the background-picture folder image/ -> Wallpaper/ and repoint all code
    (WALLPAPER_DIR, the UPDATE_FILES OTA list, comments, docstrings, the "no
    pictures" on-screen message) and docs. Add three new stock backdrops
    (Sample 11-13) to the folder and the OTA list. Config/behaviour unchanged:
    background_image stores a bare filename, still resolved inside the new folder.
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2026-07-18 v1.12.0: on-screen Wi-Fi setup in Settings → Network
    Add a "Wi-Fi Setup" button to the Network screen that opens a full touchscreen
    Wi-Fi flow (scan → pick network → on-screen keyboard for the password → connect
    → result), so the Pi can be joined to a new network without SSH or editing
    wifi.sh. New wifi_setup.py ports the nmcli logic from the Pi_dashboard project
    verbatim (scan/connect/stale-profile cleanup, persists in NetworkManager, no
    sudo needed as the service runs as root) and reimplements the UI in pygame to
    match the existing Settings menus (drawn pre-FLIP_180, hit-tested in the same
    space). Runs blocking nmcli work in daemon threads like NetworkStatus. Added to
    UPDATE_FILE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
2026-07-18 v1.12.1: Wi-Fi Setup remembers saved networks; edit a changed password
    NetworkManager already stores each network's password and auto-reconnects, but
    connect() deleted the profile every time, forcing a re-type. Now the scan marks
    networks that have a saved NM profile, and tapping a saved network connects with
    ONE tap using the stored credentials (connect_saved, no password prompt).
    For a changed router password: saved rows get an "Edit" button that opens the
    password screen to overwrite the stored password, and a failed connect on a
    secured network offers "Change password" for the same. First-time (unsaved)
    networks still prompt as before.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
2026-07-20 v1.13.0: idle-clock outline + 12/24h toggle, Day/Night backgrounds, 5s menu
    - Idle clock digits now carry a uniform black outline (matches lyric text).
    - Software Version screen gains a clock-format toggle: 24h HH:MM:SS or
    12h HH:MM AM/PM (clock_24h in config.json).
    - Background Picture: Slideshow removed; picture mode now has Day (6AM-6PM)
    and Night (6PM-6AM) slots that auto-switch on the Pi's local clock. Old
    background_image config migrates to seed both slots.
    - Settings long-press shortened from 10s to 5s.
2026-07-20 v1.13.1: move Karaoke fill to the top of the Font settings panel
    Karaoke fill (sung words) now sits above Top/Current/Bottom line. Swatch
    sizing keys off the first *sized* row's height instead of row 0, so the
    shorter colour-only Karaoke row leading the panel no longer shrinks the
    palette.

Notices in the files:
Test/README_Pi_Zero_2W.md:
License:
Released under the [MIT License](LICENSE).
